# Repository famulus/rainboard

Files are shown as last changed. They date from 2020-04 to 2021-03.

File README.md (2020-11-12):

# rainboard

An open-source isomorphic MIDI controller.

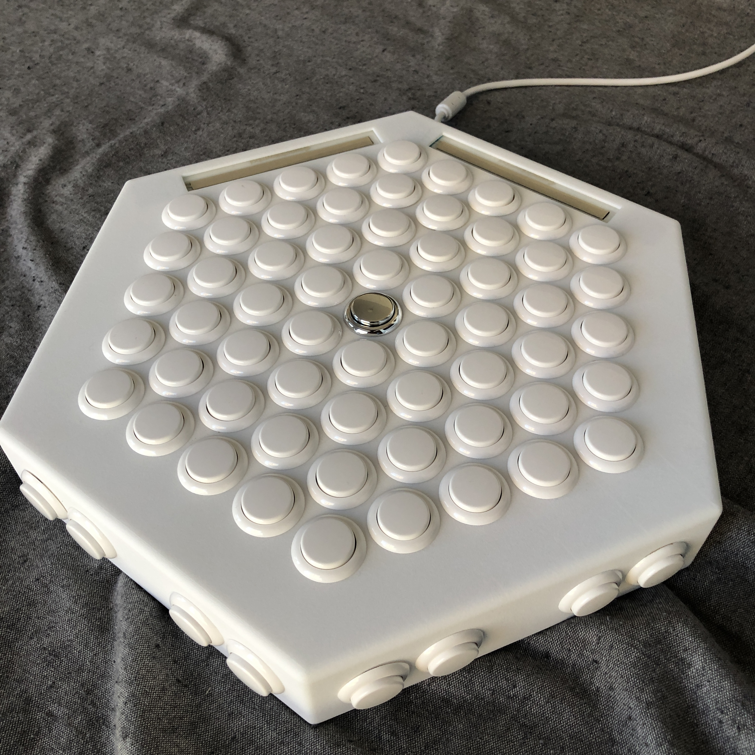
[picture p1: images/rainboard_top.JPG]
alt Rainboard


### Firmware Install:

The Rainboard firmware runs on an Arduino Mega which has two processors on board:
The main processor ( ATmega2560 ), and USB processor ( ATmega16U2 ). 

Requires an Arduino Mega with a 16U2 USB chip.

##### Installing the Rainboard firmware consists of two steps:

1. Flashing the USB controller, the ATmega16U2 with the `rainboard16U2.hex` file.
2. Uploading the main program `rainboard_firmware.ino` sketch to the Arduino Mega.

## Windows

#### Flash the USB Controller (ATmega16U2):

This can be accomplished with a DFU Programmer. Follow the instructions for your programmer.

Alternatively, if you don't have a DFU Programmer you can use Atmel FLIP software on a Windows Computer.

1. Go to http://www.atmel.com/tools/FLIP.aspx and download FLIP.
2. Install FLIP. Follow the installation wizard.
3. Disconnect Arduino from USB.
4. Jumper pins 5 and 6 on 16U2 ICSP header (as shown in fig.1). This will keep the 16U2 in RESET.
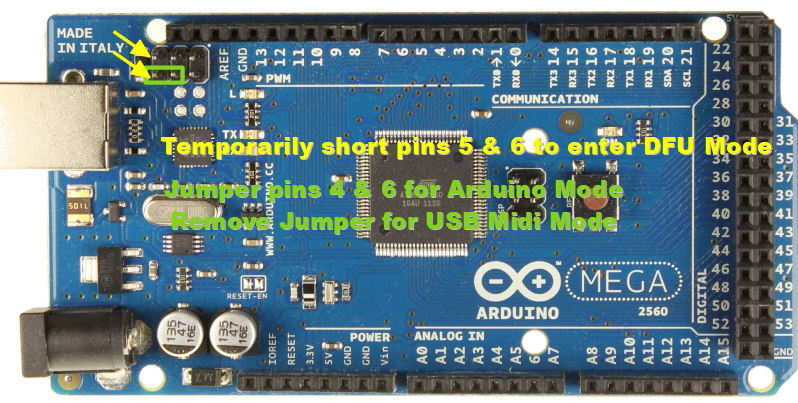
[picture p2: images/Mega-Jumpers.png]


5. Connect Arduino to USB.
6. Remove the jumper from pins 5 and 6. At this moment, 16U2 goes into DFU mode. A new USB device should be recognized.
7. If driver is not installed automatically, install it from `c:\Program Files\AtmelFlip 3.4.7\usb\`
8. Go to Device manager (Win+Pause -> (Hardware) -> Device Manager) and check if you can see the driver installed correctly. It will be located under Atmel USB Devices -> ATmega16U2.
9. Disconnect Arduino from USB. Jumper pins 5 and 6.
10. Connect Arduino to USB.
11. Remove the jumper from pins 5 and 6.
12. Start FLIP Software: Go to Start -> All Programs -> Flip -> Flip.
13. Go to Settings -> Communication -> USB.
14. Press “Open”.
15. Go to File -> Load HEX file and select the `rainboard16U2.hex` file.
16.  Press “Run”. This will program the 16U2 with the `rainboard16U2.hex` file.
17. Now close FLIP, disconnect and reconnect the Arduino, it should be recognized as a MIDI  device named Rainboard.

#### Upload firmware to the Arduino Mega (ATmega2560):

The easiest way to upload the firmware through the Arduino IDE. 
Make sure you have the proper drivers installed and that you can program the Mega from the Arduino IDE. 
You will also need two Arduino libraries installed that the Rainboard firmware depends on:

`Adafruit-MCP23017-Arduino-Library` - https://github.com/adafruit/Adafruit-MCP23017-Arduino-Library

`MIDI_Library-5.0.2` -  https://github.com/FortySevenEffects/arduino_midi_library

Make sure your Arduino environment is working, you have the two libraries installed and you can successfully compile the `rainboard_firmware.ino` sketch.  
Also make sure you have already flashed the ATmega16U2 with the `rainboard16U2.hex` file per the previous step.

1. Power down the Arduino. (unplug from host Computer)
2. Connect a jumper across pins 4 and 6 on the ICSP Header of the 16U2 (as shown in fig.1).


3. Reconnect the Arduino to the host Computer. It should appear as a COM Port Device in the Arduino IDE.
4. Now you can compile and upload the rainboard_firmware.ino sketch to the Arduino in the standard way.
5. After programming, power down (unplug from host Computer), remove the jumper from pins 4 and 6 on the   ICSP Header of the 16U2 (as shown in fig.1). The Arduino should now be fully programmed and ready to mate to the Rainboard. 
6. **Be very careful that all the pins are aligned and inserted properly before fully mating!**
7. Once the Arduino is mated to the Rainboard, reconnect it to the host PC and it should appear as a MIDI Device with the name Rainboard.

## Mac OS X

#### Flash the USB Controller (ATmega16U2):

Requires homebrew: https://brew.sh/

`brew install avrdude`

`cd [rainboard directory]/rainboard-firmware`

`avrdude -p at90usb82 -F -P usb -c usbtiny -U flash:w:rainboard16u2.hex -U lfuse:w:0xFF:m -U hfuse:w:0xD9:m -U efuse:w:0xF4:m -U lock:w:0x0F:m`

#### Upload firmware to the Arduino Mega (ATmega2560):

Same instructions as Windows.

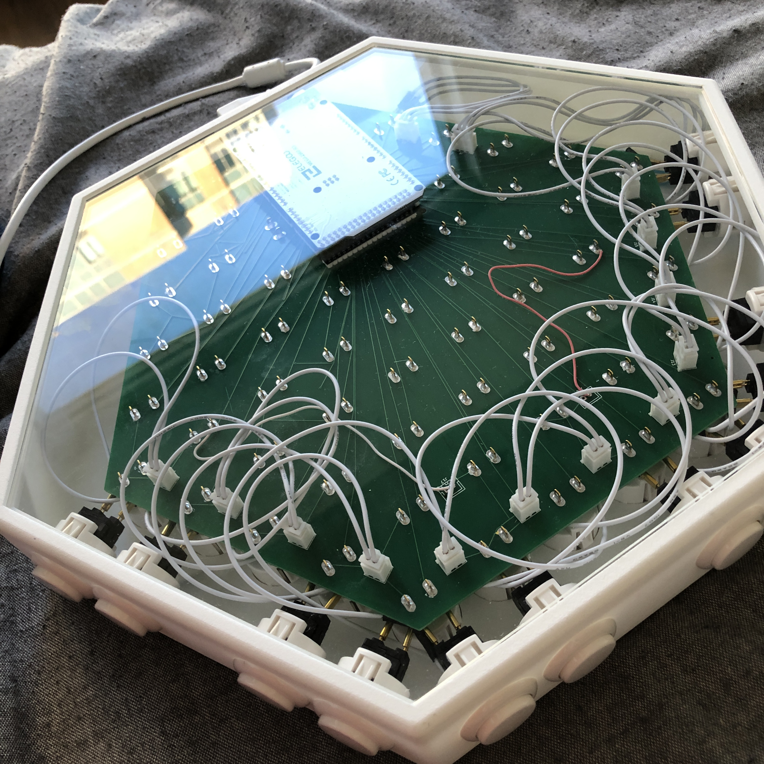
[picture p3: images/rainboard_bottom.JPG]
alt Rainboard


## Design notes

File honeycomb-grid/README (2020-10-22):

the folder uses a honeycomb-grid javascript library to generale the positions of the buttons.

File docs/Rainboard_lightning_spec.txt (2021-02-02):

Rainboard Lightning Spec

* Two versions of product will use same PCB: 

  Lightning:
    61 performance buttons (the buttons on top of unit)
    61 RGB LEDs (one LED under each button)
    12 meta-buttons (buttons on sides)
    2 softpots 
    2 MIDI DINs
    DC power input
    Sustain pedal in  
    Foot controller in
    Control Voltage out

  Thunder:
    61 main keys (RGB lEDs left unpopulated)
    USB only
    no external power supply

Take existing PCB and improve:

* Integrate Arduino Mega onto PCB.

* Implement input multiplexing (maybe remove IO expander if unnecessary).

* 61 LEDS and bypass caps.

* Power supply capable of powering 61 LEDS and Arduino, efficiently.

* When unit is powered with USB only, should still function, but without lights.

* move meta-button from front-sides to rear-sides.

* possibly engineer a better solution to connect metabuttons.

* engage programmer mode with meta buttons (or other solution).

* add 220 ohm Resistor to each button positive (for static discharge protection)?

* Redesign back panel for better aesthetic design.

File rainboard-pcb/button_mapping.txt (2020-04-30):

    button-38: D18  
    button-39: D19  
    button-44: D14  
    button-37: D17  
    button-33: A15  
    button-26: A9 A14,
    button-34: A13,
    button-35: A12  
    button-01: D31  
    button-09: D40,
    button-17: D49  
    button-25: A11 D52,
    button-41: A10  
    button-49: A5,
    button-57: D11  
    button-02: D36,
    button-10: D45  
    button-18: D51,
    button-42: A8  
    button-50: A6  
    button-58: D12,
    button-03: D38,
    button-11: D50,
    button-19: D24,
    button-27: D13,
    button-43: A7,
    button-51: D10,
    button-59: D7,
    button-04: D42,
    button-12: D26,
    button-20: D25,
    button-28: D23,
    button-36: D16  
    button-52: D9,
    button-60: A0,
    button-05: D46  
    button-13: D29,
    button-21: D28,
    button-29: D22  
    button-45: D4  
    button-53: D8  
    button-61: A2,
    button-06: D30,
    button-14: D33,
    button-22: D34  
    button-30: D27  
    button-46: D15,
    button-54: D6  
    button-07: D32  
    button-15: D39,
    button-23: D41  
    button-31: D35  
    button-47: D5  
    button-55: A1,
    button-08: D37  
    button-16: D44,
    button-24: D48  
    button-32: D47  
    button-40: D43,
    button-48: A4  
    button-56: A3

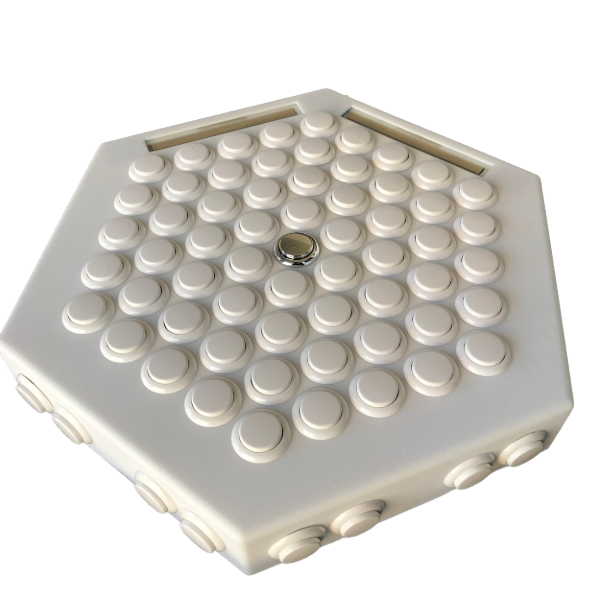
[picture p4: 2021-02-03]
website/img/not-using/rainboard_top_low-rez.png

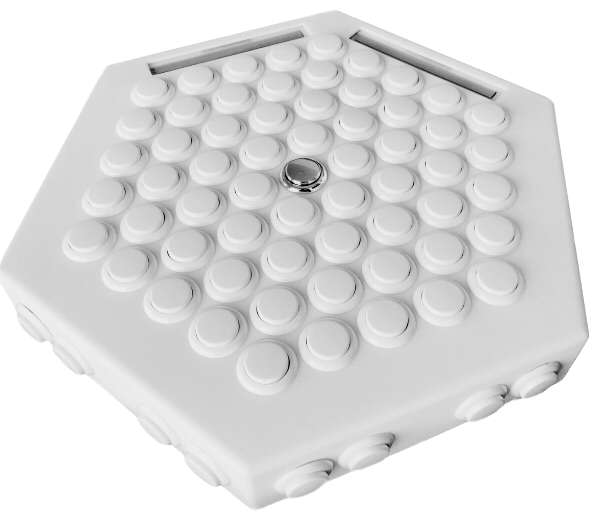
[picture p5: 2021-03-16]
website/img/rainboard-midi-controller.png

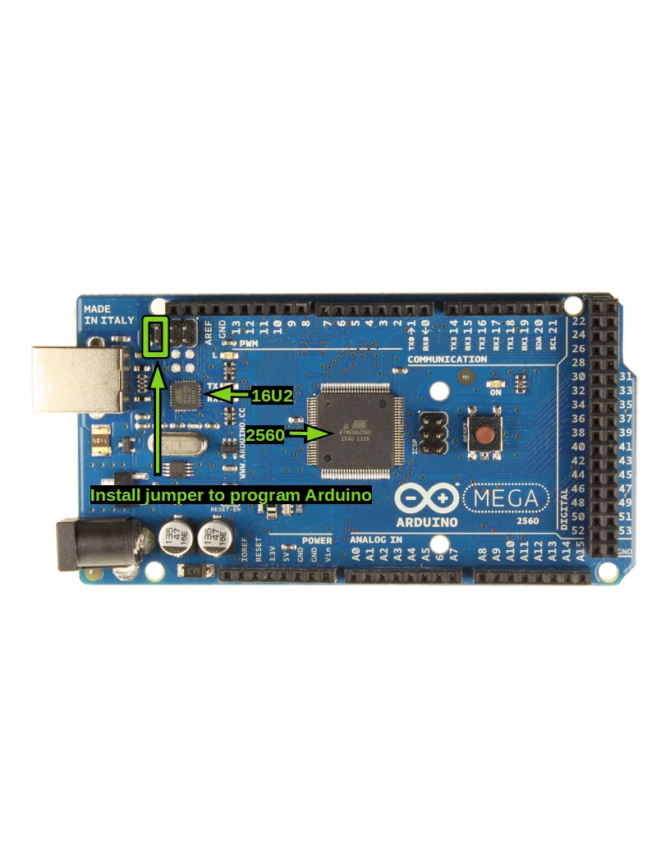
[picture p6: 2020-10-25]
images/Arduino-Mega-Photo.jpg

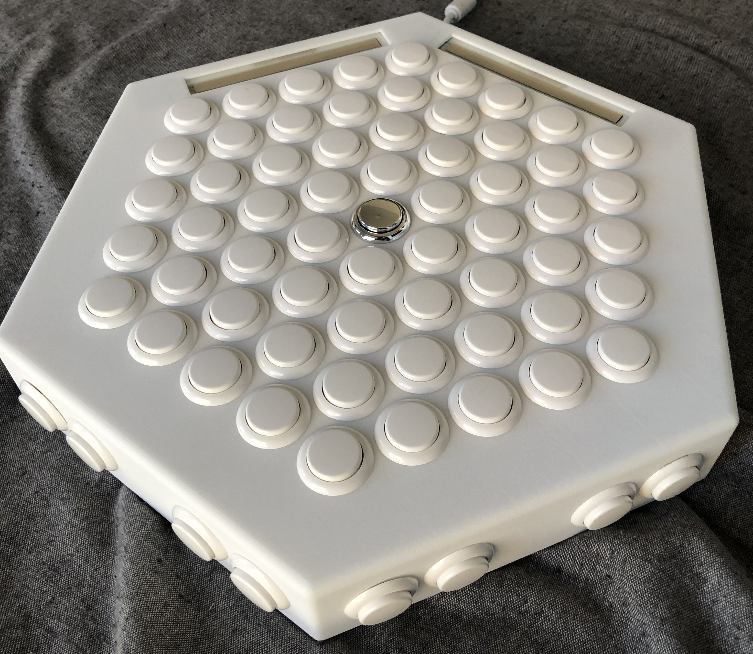
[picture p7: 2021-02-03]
website/img/not-using/rainboard_top-cropped.jpeg

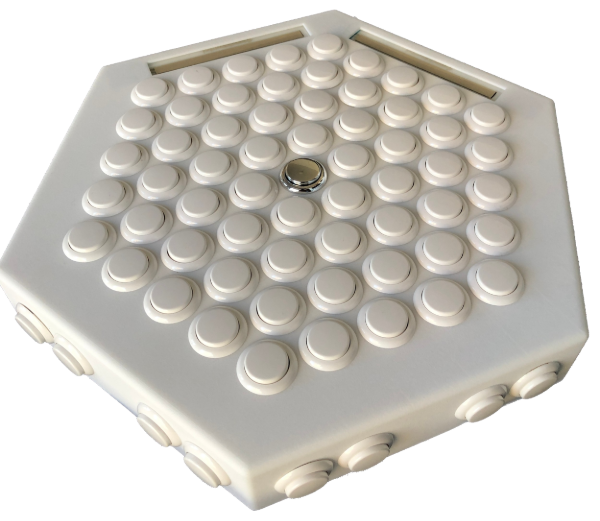
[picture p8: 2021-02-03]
website/img/not-using/rainboard_top-cropped.png

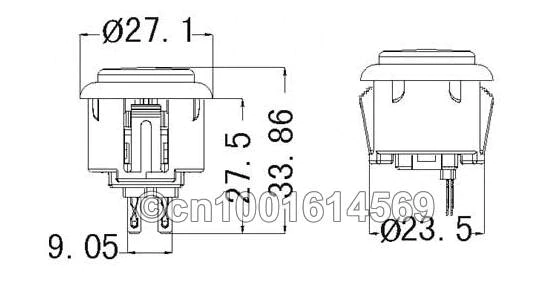
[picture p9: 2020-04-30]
honeycomb-grid/sanwa_drawing.webp

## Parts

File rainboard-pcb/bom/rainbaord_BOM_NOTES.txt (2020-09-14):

midi interface:
https://calcium3000.wordpress.com/projects/teensy-midi-interface/

io expander:
https://datasheet.lcsc.com/szlcsc/Microchip-Tech-MCP23017-E-SO_C47023.pdf
https://www.best-microcontroller-projects.com/mcp23017.html

1uf caps:

https://datasheet.lcsc.com/szlcsc/Samsung-Electro-Mechanics-CL21B105KBFNNNE_C28323.pdf

100k resistor:

https://lcsc.com/product-detail/Chip-Resistor-Surface-Mount_Uniroyal-Elec-1206W4F1003T5E_C17900.html/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

10K resistor:

1206W4F1002T5E
https://datasheet.lcsc.com/szlcsc/Uniroyal-Elec-1206W4F1002T5E_C17902.pdf

4.7K
0603WAF4701T5E

softpot connectors:
https://learn.sparkfun.com/tutorials/softpot-hookup-guide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

schmitt trigger:
https://calcium3000.wordpress.com/projects/teensy-midi-interface/
https://components101.com/articles/schmitt-trigger-introduction-working-applications
https://datasheet.lcsc.com/szlcsc/Nexperia-74HCT14D-653_C5967.pdf

optocoupler:
https://hackaday.com/2018/05/09/optocouplers-defending-your-microcontroller-midi-and-a-hot-tip-for-speed/
https://datasheet.lcsc.com/szlcsc/Everlight-Elec-EL357N-B-TA-G_C6649.pdf

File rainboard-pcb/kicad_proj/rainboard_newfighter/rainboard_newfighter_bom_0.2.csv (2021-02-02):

Component | Description | Part | References | Value | Footprint | Quantity Per PCB | Datasheet | LCSC | PN
1 | Unpolarized capacitor | C | C7 C9 C13 C18 C29 C30 C32 C34 C35 C37 C40 C41 C44 C45 C46 C49 C50 C65 C66 C67 C68 C69 C70 C71 C72 C73 C74 C75 C76 C77 C78 C79 C80 C81 C82 C83 C84 C85 C86 C87 C88 C89 C90 C91 C92 C93 C94 C95 C96 C97 C98 C99 C100 C101 C102 C103 C104 C105 C106 C107 C108 C109 C110 C111 C112 C113 C114 C115 C116 C117 C118 C119 C120 C121 | 100nf | C_0603_1608Metric | 74 | ~ | C14663 | CC0603KRX7R9BB104
2 | Unpolarized capacitor | C | C3 C4 C6 C21 C22 C24 C25 C26 C27 C55 C56 C57 C58 C59 C60 C61 C62 C63 C64 | 10uF 25V | C_1206_3216Metric | 19 | ~ |  | CL21B105KBFNNNE
3 | Unpolarized capacitor | C | C5 C8 C10 C11 C12 C14 C16 C17 C20 C23 C31 C33 C36 C38 C39 C43 C47 C48 | 1uF 25V | C_0805_2012Metric | 18 | ~ |  | CL21B105KBFNNNE
4 | Polarized capacitor | CP | C15 C19 C28 C42 C51 C52 C53 C54 | 470uF 25V | CP_Elec_10x10 | 8 | ~ |  | UCW1E471MNL1GS
5 | Unpolarized capacitor | C | C1 C2 | DNP-1uF 25V | C_0805_2012Metric | 2 | ~ |  | DNP-CL21B105KBFNNNE
6 | Zener diode | D_Zener | D1 D6 | 12Vw | D_SMA | 2 | ~ |  | SMAJ12A
7 | Schottky diode | D_Schottky | D8 D10 D11 D12 D16 D17 D18 | 40V 1A | D_SOD-123 | 7 | ~ |  | PMEG4010EGWJ
8 | Dual Zener diode, common anode on pin 3 | D_Zener_x2_ACom_KKA | D2 D3 D4 D9 D13 D14 D15 | 5Vw | SOT-23 | 7 | ~ |  | S2305TR
9 | Zener diode | D_Zener | D5 D7 | 5Vw | D_SMA | 2 | ~ |  | SMAJ5.0A
10 | RGB LED with integrated controller | WS2812B | D19 D20 D21 D22 D23 D24 D25 D26 D27 D28 D29 D30 D31 D32 D33 D34 D35 D36 D37 D38 D39 D40 D41 D42 D43 D44 D45 D46 D47 D48 D49 D50 D51 D52 D53 D54 D55 D56 D57 D58 D59 D60 D61 D62 D63 D64 D65 D66 D67 D68 D69 D70 D71 D72 D73 D74 D75 | WS2812B | LED_WS2812B_PLCC4_5.0x5.0mm_P3.2mm | 57 | https://cdn-shop.adafruit.com/datasheets/WS2812B.pdf |  | WS2812B
11 | Resettable fuse, polymeric positive temperature coefficient | Polyfuse | F2 | 15V .5A | Fuse_1812_4532Metric | 1 | ~ |  | MF-MSMF050-2
12 | Resettable fuse, polymeric positive temperature coefficient | Polyfuse | F1 | 20V 3A | Fuse_1812_4532Metric | 1 | ~ |  | TLC-MSMD150/20
13 | Ferrite bead | Ferrite_Bead | FB1 FB2 FB3 | 4A Ferrite | L_1206_3216Metric | 3 | ~ |  | 742792115
14 | Generic connector, single row, 01x02, script generated (kicad-library-utils/schlib/autogen/connector/) | Conn_01x02_Female | J4 J5 J6 J7 J8 J9 J10 J11 J12 J13 J14 J15 J16 J17 J18 J20 | Conn_01x02_Female | JST_XH_B2B-XH-A_1x02_P2.50mm_Vertical | 16 | ~ |  | B2B-XH-A(LF)(SN)
15 | Generic connector, single row, 01x03, script generated (kicad-library-utils/schlib/autogen/connector/) | Conn_01x03 | J22 J23 | Conn_01x03 | JST_XH_B3B-XH-AM_1x03_P2.50mm_Vertical | 2 | ~ |  | B3B-XH-AM
16 | DC Barrel Jack with an internal switch | Barrel_Jack_Switch | J1 | EJ508A | BarrelJack_Horizontal | 1 | ~ |  | EJ508A
17 | Generic connector, double row, 02x03, odd/even pin numbering scheme (row 1 odd numbers, row 2 even numbers), script generated (kicad-library-utils/schlib/autogen/connector/) | Conn_02x03_Odd_Even | J21 J24 J25 | PH2-06-UA | PinHeader_2x03_P2.54mm_Vertical | 3 | ~ |  | PH2-06-UA
18 | CONN RCPT FMALE DIN 5POS SOLDER | SDS-50J | J2 J19 | SDS-50J | CUI_SDS-50J | 2 | CUI Inc |  | SDS-50J
19 | USB Type B connector | USB_B | J3 | USB_B | UJ2-BH-1-TH | 1 | ~ |  | UJ2-BH-1-TH
20 | Jumper, normally closed | Jumper | JP1 JP2 JP3 JP4 JP5 | Jumper | SolderJumper-2_P1.3mm_Bridged_Pad1.0x1.5mm | 5 | ~ |  | Virtual
21 | Inductor | L | L2 L4 L5 | 10uH .5Ohm | INDC250X180X200L50N | 3 | ~ |  | CBC2518T100K
22 | Inductor | L | L1 L3 | 27uH | L_12x12mm_H8mm | 2 | ~ |  | SRR1210-270M
23 | Generic PowerPAK-8 1212-8 | NMOS_SGD_123_4_5 | Q1 | 30V 10mOhm | PowerPAK_SO-8_Single | 1 |  |  | SI7114ADN-T1-GE3
24 | Dual NMOS transistor, 6 pin package | Q_DUAL_NMOS_S1G1D2S2G2D1 | Q2 Q3 | DUAL 30V NMOS | SOT-363_SC-70-6 | 2 |  |  | DMN3190LDW
25 | Resistor | R | R7 R13 R14 R17 R19 R35 R36 | 100k | R_0603_1608Metric | 7 | ~ | C25803 | RC0603JR-07100KL
26 | Resistor | R | R2 R3 R4 R5 R6 R11 R25 R42 R43 R47 R49 R51 R53 | 11R | R_0603_1608Metric | 13 | ~ | C227565 | RC0603JR-0711RL
27 | Resistor | R | R10 R12 R20 R22 R23 R24 R28 R29 R31 R32 R39 R40 R48 R50 R52 | 19.1k | R_0603_1608Metric | 15 | ~ | C22897 | RC0603FR-0719K1L
28 | Resistor | R | R1 R8 R15 R21 R26 R54 R55 R56 R57 R58 R59 R60 R61 R62 R63 R64 R65 R66 R67 R68 R69 R70 R71 R72 R73 R74 R75 R76 R77 R78 R79 R80 R81 R82 R83 R84 R85 R86 R87 R88 R89 R90 R91 R92 R93 R95 R96 R97 R98 R99 R100 R101 R102 R103 R104 R105 R106 R107 R108 R109 R110 | 210R | R_0805_2012Metric | 61 | ~ | C228630 | RC0603FR-07210RL
29 | Resistor | R | R111 R112 R113 R114 R115 R116 R117 R118 R119 R120 R121 R122 R123 R124 R125 R126 R127 R128 R129 R130 R131 R132 R133 R134 R135 R136 R137 R138 R139 R140 R141 R142 R143 R144 R145 R146 R147 R148 R149 R150 R151 R152 R153 R154 R155 R156 R157 R158 R159 R160 R161 R162 R163 R164 R165 R166 R167 | 210R | R_0805_2012Metric | 57 | ~ | C228630 | RC0603FR-07210RL
30 | Resistor | R | R9 R18 R27 R30 R33 R34 R37 R38 R41 R44 R46 | 4.7k | R_0603_1608Metric | 11 | ~ | C23162 | RC0603JR-074K7L
31 | Resistor | R | R16 | DNP-210R | R_0805_2012Metric | 1 | ~ | DNP-C228630 | RC0603FR-07210RL
32 | Resistor | R | R45 | DNP-4.7k | R_0603_1608Metric | 1 | ~ | DNP-C23162 | RC0603JR-074K7L
33 | 24mm Joystick Button | SANWA-OBSF24 | SW1 SW2 SW3 SW4 SW5 SW6 SW7 SW8 SW9 SW10 SW11 SW12 SW13 SW14 SW15 SW16 SW17 SW18 SW19 SW20 SW21 SW22 SW23 SW24 SW25 SW26 SW27 SW28 SW29 SW30 SW31 SW32 SW33 SW34 SW35 SW36 SW37 SW38 SW39 SW40 SW41 SW42 SW43 SW44 SW45 SW46 SW47 SW48 SW49 SW50 SW51 SW52 SW53 SW54 SW55 SW56 SW57 | SANWA-OBSF24 | Sanwa-OBSF24-v2 | 57 |  |  | SANWA-OBSC-CW/W
34 | Single High Speed LSTTL/TTL Compatible Optocoupler with enable, dV/dt 1000/us, VCM 10, max 7V VCC, DIP-8 | 6N137 | U1 | 6N137 | COUPL_6N138SDM | 1 | https://www.onsemi.com/pub/Collateral/HCPL2631M-D.pdf |  | 6N137SDM
35 | Hex inverter schmitt trigger | 74HC14 | U3 | 74HC14 | TSSOP-14_4.4x5mm_P0.65mm | 1 | http://www.ti.com/lit/gpn/sn74HC14 |  | 74HC14PW-Q100,118
36 | 16MHz, 16kB Flash, 512B SRAM, 512B EEPROM, QFN-32 | ATmega16U2-MU | U4 U5 | ATmega16U2-MU | QFN-32-1EP_5x5mm_P0.5mm_EP3.1x3.1mm | 2 | http://ww1.microchip.com/downloads/en/DeviceDoc/doc7799.pdf |  | ATMEGA16U2-MUR
37 | 8MHz, 64kB Flash, 8kB SRAM, 4kB EEPROM, JTAG, TQFP-100 | ATmega2560-16AU | U6 | ATmega2560-16AU | TQFP-100_14x14mm_P0.5mm | 1 | http://ww1.microchip.com/downloads/en/DeviceDoc/Atmel-2549-8-bit-AVR-Microcontroller-ATmega640-1280-1281-2560-2561_datasheet.pdf |  | ATMEGA2560-16AUR
38 | Buck Switching Regulator IC Positive Adjustable 0.8V 1 Output 6A 8-SOIC (0.154", 3.90mm Width) Exposed Pad | RT8298 | U2 | RT8298 | SOIC-8-1EP_3.9x4.9mm_P1.27mm_EP2.41x3.3mm_ThermalVias | 1 | ~ |  | RT8298ZSP
39 | Three pin ceramic resonator | Resonator | Y1 Y2 Y3 | 16MHz | Resonator_SMD_muRata_CSTxExxV-3Pin_3.0x1.1mm | 3 | ~ |  | CSTNE16M0V530000R0
Component Groups: | 39
Component Count: | 471
Fitted Components: | 471
Number of PCBs: | 1
Total components: | 471
Schematic Version: | 0.2
Schematic Date:
PCB Variant: | default
BoM Date: | 1/14/2021 10:12:15 AM
Schematic Source: | rainboard_newfighter.sch
KiCad Version: | Eeschema (5.1.5)-3

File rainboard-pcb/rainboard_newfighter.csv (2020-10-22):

Comment | Designator | Footprint | LCSC
100nf | C1,C2,C3,C4 | Capacitor_SMD:C_0603_1608Metric | C14663
D | D1 | Diode_SMD:D_SMA | C95872
Conn_01x02 | J1,J2,J3,J4,J5,J6,J7,J8,J13,J14,J15,J16,J17,J18 | Connector_JST:JST_XH_B2B-XH-AM_1x02_P2.50mm_Vertical
Conn_01x03 | J9,J10 | Connector_JST:JST_XH_B3B-XH-AM_1x03_P2.50mm_Vertical
SDS-50J | J11,J12 | MIDI-DIN:CUI_SDS-50J
100k | R1,R2 | Resistor_SMD:R_0603_1608Metric | C25803
4.7k | R3,R4,R9,R10 | Resistor_SMD:R_0603_1608Metric | C23162
220R | R5,R6,R7 | Resistor_SMD:R_0603_1608Metric | C22962
10k | R8 | Resistor_SMD:R_0603_1608Metric | C25804
SANWA-OBSF24 | S1,S2,S3,S4,S5,S6,S7,S8,S9,S10,S11,S12,S13,S14,S15,S16,S17,S18,S19,S20,S21,S22,S23,S24,S25,S26,S27,S28,S29,S30,S31,S32,S33,S34,S35,S36,S37,S38,S39,S40,S41,S42,S43,S44,S45,S46,S47,S48,S49,S50,S51,S52,S53,S54,S55,S56,S57,S58,S59,S60,S61 | rainboard_newfighter:Sanwa-OBSF24-v2
MCP23017-E_SO | U1 | io_expander:SOIC127P1030X265-28N | C47023
74HC14D | U2 | schmitt_trigger:SOIC127P600X175-14N | C5605
EL357N(A)(TA)-G | U3 | opto_coupler:SOP254P700X200-4N | C142286
Arduino_Mega2560_Shield | XA1 | arduno_mega:Arduino_Mega2560_Shield

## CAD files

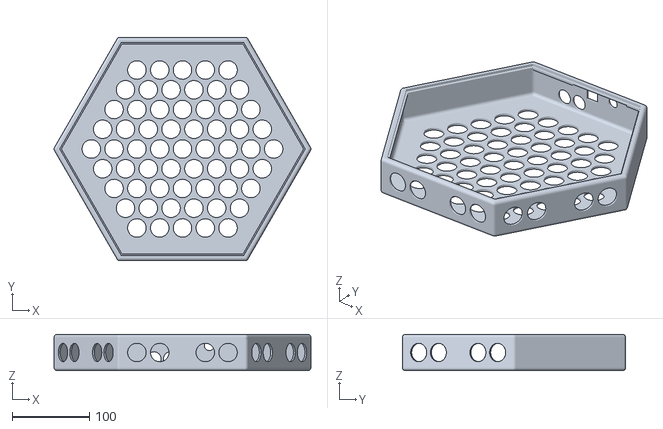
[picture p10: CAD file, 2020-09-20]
3D_Printed_chassis/rainboard_chassis.stl
332.6 x 289.1 x 46.9

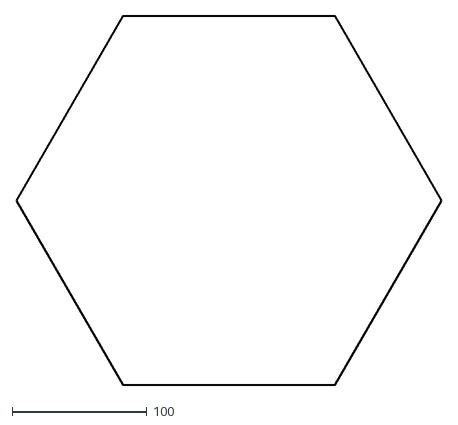
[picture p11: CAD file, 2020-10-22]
rainboard-chassis/lightning/plexi_bottom.dxf
316.4 x 274.0

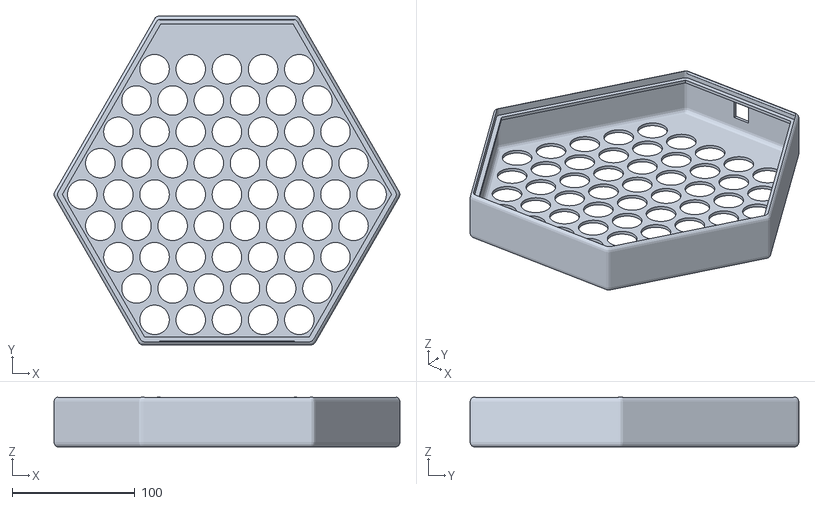
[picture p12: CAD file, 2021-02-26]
rainboard-chassis/thunder/rainboard_chassis_thunder.stl
282.1 x 268.2 x 40.7

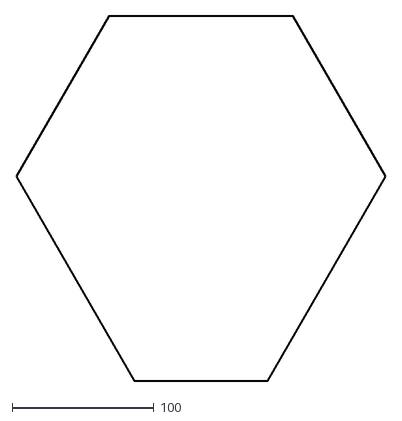
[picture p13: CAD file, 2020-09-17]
rainboard-pcb/edgecut.dxf
260.0 x 256.6

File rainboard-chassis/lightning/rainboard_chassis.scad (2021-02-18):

round_over = 4;
wall_thickness = 3 ;

rainboad_diameter = 332.55  ; // point to point, long diagonal  288 short diag
rainboard_height = 41;

hole_radius = 12;

resolution = 100;

back_panel = [125,40,60];

foot_inset = 15;





module backPanel(dimentions=[1,2,3]) {

  midi_opening = 18.5; //diameter
  midi_horizontal_offset = 38.9735;    
  usb_width = 14.5;    //cube_width
  usb_opening = [usb_width,usb_width,10] ;
  
  dc_power_opening = 13; // diameter
  dc_power_horizontal_offset = -38.1765;    
  
  top_of_chassis_to_top_of_pcb = 25;    
  
  pcb_offset = top_of_chassis_to_top_of_pcb -(rainboard_height/2);
  
  translate([0,((288/2)-1.5),pcb_offset]) rotate([90,0,0]){ // place all holes at the back panel
    
   translate([ 0, -(usb_width/2),0]) cube(usb_opening, center=true); // cutout for USB
   translate([midi_horizontal_offset,-(dc_power_opening/2),0]) cylinder(20, d=(dc_power_opening), center=true,$fn=resolution);  // cutout for power   

   translate([dc_power_horizontal_offset,-(midi_opening/2),0]) cylinder(20, d=(midi_opening), center=true,$fn=resolution);   // midi OUT  
   
 }   
 

}



module mainBody(rainboard_height,rainboad_diameter, round_over ) {

  minkowski(){
    
    //            main body
    
    cylinder(h=rainboard_height-(round_over*2), d=(rainboad_diameter- (round_over*2)), center=true,$fn=6);     
    
    //            round over
    sphere(round_over, $fn=resolution);

  }

}


module interior(rainboard_height,rainboad_diameter, round_over, wall_thickness ) {

  //        interior
  
  translate([0,0,0])
  minkowski(){
    
    //            interior hex
    //        cylinder(h=(rainboard_height+ wall_thickness), d=(rainboad_diameter - wall_thickness), center=true,$fn=6);
    cylinder(h=rainboard_height-(round_over*2)-(wall_thickness*2) , d=((rainboad_diameter- (round_over*2)) -(wall_thickness*2) ), center=true,$fn=6);     

    
    //            round over
    sphere(round_over, $fn=resolution);

  };

}

module footer_cutout(rainboard_height,rainboad_diameter, foot_inset ) {
  translate([0,0,foot_inset])
  cylinder(h=rainboard_height+foot_inset , d=(rainboad_diameter-foot_inset), center=true,$fn=6);     


}



module buttons(buttons ) {

  //    button
  
  
  for(i = buttons){
    translate([i[0],i[1],-50])cylinder(r=12, h=100, $fn=resolution);
  };
}





module ledge( ) {    // ledge for plexiglass

  plexi_thickness = 3; 
  recess = 2; 

  difference (){
    
   translate([0,0,  (rainboard_height/2 - (plexi_thickness/2)-plexi_thickness-recess)  ])    cylinder(h=plexi_thickness , d=(rainboad_diameter  ), center=true,$fn=6);   // the ledge  
   


   translate([0,0,rainboard_height/2 - 3-2])   cylinder(h=20 , d=(rainboad_diameter-foot_inset-4), center=true,$fn=6);     // the cutout negative



 }

}




module sideButtons(buttons ) {

  //    button
  for(i = [-2:2]){
    if(i != 0){
      translate([i*29.5,-100,0]) rotate([90,0,0])  cylinder(r=12, h=100, $fn=resolution);
    }
  }
}













module modulation_strips_positive( ) {


  //  https://cdn-shop.adafruit.com/product-files/178/SOFTPOT-DATA-SHEET-Rev-F3.pdf
  tolerance = 1;
  half_tolerance = tolerance /2;
  ribbonLength =  115.86+ tolerance;
  ribbonWidth = 20.32+ tolerance;
  ribbonThickness = 0.58+ tolerance;
  tailLength = 24.89+ tolerance;
  tailWidth  = 10.16+ tolerance;    
  softpot_backer =     2;
  softpot_wall_thickness = 1.5;


  rotate([0,180,0]) 
  translate([0,288/2-16.7,
    ((rainboard_height/2)-(softpot_wall_thickness*2))
    ])
  cube(
    [
    ribbonLength+(softpot_wall_thickness*2),
    ribbonWidth+(softpot_wall_thickness*2.5),
    softpot_backer+(softpot_wall_thickness)
    ]
    , true); // enclosing cuboid
  
  
  rotate([0,180,300]) 
  translate([0,288/2-16.7,
    ((rainboard_height/2)-(softpot_wall_thickness*2))
    ])
  cube(
    [
    ribbonLength+(softpot_wall_thickness*2),
    ribbonWidth+(softpot_wall_thickness*2.5),
    softpot_backer+(softpot_wall_thickness)
    ]
    , true); // enclosing cuboid
  
  
}





module modulation_strips_negative( ) {


  //  https://cdn-shop.adafruit.com/product-files/178/SOFTPOT-DATA-SHEET-Rev-F3.pdf
  tolerance = 1;
  half_tolerance = tolerance /2;
  ribbonLength =  115.86+ tolerance;
  ribbonWidth = 20.32+ tolerance;
  ribbonThickness = 0.58+ tolerance;
  tailLength = 24.89+ tolerance;
  tailWidth  = 10.16+ tolerance;    
  slot_height =     1.6;
  slot_runout = 46;    
  active_area_width =   15;
  active_area_length =   110;  
  softpot_wall_thickness = 1.5;


  rotate([0,180,0]) 
  translate([0,288/2-16.7,
    ((rainboard_height/2)-(softpot_wall_thickness)-softpot_wall_thickness/2)
    ]){
    
    cube([ribbonLength+slot_runout,ribbonWidth,slot_height], true); // slot for ribbon

    translate([0,0,10])cube([active_area_length,active_area_width,20], true); // smaller cutout for active area
  }
  
  
  rotate([0,180,300]) 
  translate([0,288/2-16.7,
    ((rainboard_height/2)-(softpot_wall_thickness)-softpot_wall_thickness/2)
    ]){
    
    cube([ribbonLength+slot_runout,ribbonWidth,slot_height], true); // slot for ribbon

    translate([0,0,10])cube([active_area_length,active_area_width,20], true); // smaller cutout for active area
  }
  
  



}

















//  Final Output
difference(){
  difference(){
    mainBody(rainboard_height,rainboad_diameter, round_over );                   
    interior(rainboard_height,rainboad_diameter, round_over, wall_thickness );
  };
  
  footer_cutout(rainboard_height,rainboad_diameter, foot_inset);

  backPanel(back_panel);

  
  rotate([0,0,120])sideButtons();
  rotate([0,0,240])sideButtons();
  rotate([0,0,0])sideButtons();
  


  buttons(buttons_coordinates);

  backPanel();

  
  modulation_strips_negative();

};

ledge();


difference (){
  modulation_strips_positive();
  modulation_strips_negative();

}




buttons_coordinates =

[
[  -117.98730101159192,  0 ],
[  -103.23888838514293,  25.545 ],
[  -88.49047575869395,  51.09 ],
[  -73.74206313224495,  76.635 ],
[  -58.99365050579596,  102.18 ],
[  -103.23888838514293,  -25.545 ],
[  -88.49047575869395,  0 ],
[  -73.74206313224495,  25.545 ],
[  -58.99365050579596,  51.09 ],
[  -44.24523787934697,  76.635 ],
[  -29.49682525289798,  102.18 ],
[  -88.49047575869395,  -51.09 ],
[  -73.74206313224495,  -25.545 ],
[  -58.99365050579596,  0 ],
[  -44.24523787934697,  25.545 ],
[  -29.49682525289798,  51.09 ],
[  -14.74841262644899,  76.635 ],
[  0,  102.18 ],
[  -73.74206313224495,  -76.635 ],
[  -58.99365050579596,  -51.09 ],
[  -44.24523787934697,  -25.545 ],
[  -29.49682525289798,  0 ],
[  -14.74841262644899,  25.545 ],
[  0,  51.09 ],
[  14.74841262644899,  76.635 ],
[  29.49682525289798,  102.18 ],
[  -58.99365050579596,  -102.18 ],
[  -44.24523787934697,  -76.635 ],
[  -29.49682525289798,  -51.09 ],
[  -14.74841262644899,  -25.545 ],
[  0,  0 ],
[  14.74841262644899,  25.545 ],
[  29.49682525289798,  51.09 ],
[  44.24523787934697,  76.635 ],
[  58.99365050579596,  102.18 ],
[  -29.49682525289798,  -102.18 ],
[  -14.74841262644899,  -76.635 ],
[  0,  -51.09 ],
[  14.74841262644899,  -25.545 ],
[  29.49682525289798,  0 ],
[  44.24523787934697,  25.545 ],
[  58.99365050579596,  51.09 ],
[  73.74206313224495,  76.635 ],
[  0,  -102.18 ],
[  14.74841262644899,  -76.635 ],
[  29.49682525289798,  -51.09 ],
[  44.24523787934697,  -25.545 ],
[  58.99365050579596,  0 ],
[  73.74206313224495,  25.545 ],
[  88.49047575869395,  51.09 ],
[  29.49682525289798,  -102.18 ],
[  44.24523787934697,  -76.635 ],
[  58.99365050579596,  -51.09 ],
[  73.74206313224495,  -25.545 ],
[  88.49047575869395,  0 ],
[  103.23888838514293,  25.545 ],
[  58.99365050579596,  -102.18 ],
[  73.74206313224495,  -76.635 ],
[  88.49047575869395,  -51.09 ],
[  103.23888838514293,  -25.545 ],
[  117.98730101159192,  0 ]
];

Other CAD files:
rainboard-chassis/thunder/rainboard_chassis_thunder.scad

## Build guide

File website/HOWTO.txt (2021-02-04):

TO DEPLOY UPDATES TO SURGE:
====================

Deploying first time? Get surge:

$ npm install --global surge

Learn more:
https://surge.sh/help/getting-started-with-surge

Deploy:

$ surge --domain https://rainboard.surge.sh

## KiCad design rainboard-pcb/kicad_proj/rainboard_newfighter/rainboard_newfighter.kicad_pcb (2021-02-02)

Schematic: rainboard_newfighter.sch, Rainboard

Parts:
C1, C2: DNP-1uF 25V
C5, C10, C14, C17, C23, C31, C33, C36, C38, C39, C43, C47, C48: 1uF 25V; C_0805_2012Metric
C7, C13, C18, C29, C30, C32, C34, C35, C37, C40, C41, C44, C45, C46, C49, C50: 100nf; C_0603_1608Metric; LCSC C14663
C11: 1uF 25V
C15, C19, C42: 470uF 10V; CP_Elec_6.3x7.7
D1, D6: 6V; SOT23-3
D2, D4, D9, D13, D14, D15: 5Vw; SOT-23
D3: 5Vw
D5, D7: 5Vw; D_SMA
D10, D11, D12, D16, D17, D18: 40V 1A; D_SOD-123
F1: 12V 5A; Fuse_2010_5025Metric
F2: 15V .5A; Fuse_1812_4532Metric
FB1, FB3: 4A Ferrite; L_1206_3216Metric
FB2: 10A Ferrite; L_1210_3225Metric
J1: 54-00167; BarrelJack_Horizontal
J2: SDS-50J
J3: USB_B; UJ2-BH-1-TH
J4, J5, J6, J7, J8, J9, J10, J11, J12, J13, J14, J16: Conn_01x02_Female; JST_XH_B2B-XH-A_1x02_P2.50mm_Vertical
J15: SDS-50J; CUI_SDS-50J
J17, J20, J21: PH2-06-UA; PinHeader_2x03_P2.54mm_Vertical
J18, J19: Conn_01x03; JST_XH_B3B-XH-AM_1x03_P2.50mm_Vertical
JP1, JP2, JP3, JP4, JP5: Jumper; SolderJumper-2_P1.3mm_Bridged_Pad1.0x1.5mm
L1: 27uH; L_12x12mm_H8mm
L2, L4, L5: 10uH .5Ohm; INDC250X180X200L50N
Q2, Q3: DUAL 30V NMOS; SOT-363_SC-70-6
R1, R8: 210R; LCSC C228630
R2, R3, R5, R6, R11, R25, R42, R43, R47, R49, R51, R53: 11R; R_0603_1608Metric; LCSC C227565
R4: 11R; LCSC C227565
R9, R18, R27, R30, R33, R34, R37, R38, R41, R44, R46: 4.7k; R_0603_1608Metric; LCSC C23162
R10, R12, R22, R23, R24, R28, R29, R31, R32, R39, R40, R48, R50, R52: 19.1k; R_0603_1608Metric; LCSC C22897
R14, R35, R36: 100k; R_0603_1608Metric; LCSC C25803
R15, R21, R26: 210R; R_0805_2012Metric; LCSC C228630
R16: DNP-210R; R_0805_2012Metric; LCSC DNP-C228630
R45: DNP-4.7k; R_0603_1608Metric; LCSC DNP-C23162
TP1, TP2, TP3, TP4, TP5, TP6, TP7, TP8, TP9, TP10, TP11, TP12, TP13, TP14, TP15, TP16, TP17, TP18, TP19, TP20, TP21, TP22, TP23, TP24, TP25, TP26: TestPoint; TestPoint_Pad_1.0x1.0mm
U1: 6N137
U3: 74HC14; TSSOP-14_4.4x5mm_P0.65mm
U4: ATmega16U2-MU; QFN33P50_500X500X60L40X24T300N
U5: ATmega16U2-MU; QFN-32-1EP_5x5mm_P0.5mm_EP3.1x3.1mm
U6: ATmega2560-16AU; TQFP-100_14x14mm_P0.5mm
Y1, Y2, Y3: 16MHz; Resonator_SMD_muRata_CSTxExxV-3Pin_3.0x1.1mm

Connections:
5VA_MCU: C41.1, C42.1, L5.1, R37.1, U6.100 (AVCC)
5V_MCU: C11.1, C17.1, C19.1, C23.1, C36.1, C37.1, C39.1, C40.1, C48.1, C49.1, D10.1 (K), D11.1 (K), D16.1 (K), D17.1 (K), D18.1 (K), J17.2, J20.2, J21.2, L5.2, R8.2, R9.1, R18.1, R25.1, R27.1, R30.1, R39.1, R40.1, R46.1, R48.2, U1.7 (EN), U1.8 (VCC), U3.14 (VCC), U4.4 (VCC), U4.32 (AVCC), U5.4 (VCC), U5.32 (AVCC), U6.10 (VCC), U6.31 (VCC), U6.61 (VCC), U6.80 (VCC)
5V_USB: C14.1, C33.1, C35.1, C43.1, C44.1, D7.1 (K), D11.2 (A), FB3.2, JP3.1, U4.31 (UVCC)
5V_WALL: C13.1, C15.1, D6.3 (NC), FB2.1, JP1.1, L4.2, R14.1
/PCBMountButtons/FIRST_DIN: D12.2 (A), R15.2, R16.2, R22.1; also elsewhere on the board
AREF: C29.1, C47.1, D15.1 (K), J18.1, J19.1, R37.2, U6.98 (AREF)
BARREL_DETECT: C18.1, R14.2, R50.1, R52.1
BREF: D15.2 (K), J18.3, J19.3, R38.1, U6.86 (PK3)
BTN1a: R10.1, U6.59 (PC6)
BTN1b: R12.1, U5.5 (PC2)
BTN2a: R23.1, U6.55 (PC2)
BTN2b: R24.1, U5.26 (PC4)
BTN3a: R28.1, U6.50 (PD7)
BTN3b: R29.1, U5.25 (PC5)
BTN4a: R31.1, U6.42 (PL7)
BTN4b: R32.1, U5.23 (PC6)
BTN5: U6.38 (PL3); also elsewhere on the board
BTN6: U6.60 (PC7); also elsewhere on the board
BTN7: U6.58 (PC5); also elsewhere on the board
BTN8: U6.54 (PC1); also elsewhere on the board
BTN9: U6.52 (PG1); also elsewhere on the board
BTN10: U6.40 (PL5); also elsewhere on the board
BTN11: U6.7 (PE5); also elsewhere on the board
BTN12: U6.74 (PA4); also elsewhere on the board
BTN13: U6.71 (PA7); also elsewhere on the board
BTN14: U6.57 (PC4); also elsewhere on the board
BTN15: U6.70 (PG2); also elsewhere on the board
BTN16: U6.39 (PL4); also elsewhere on the board
BTN17: U6.36 (PL1); also elsewhere on the board
BTN18: U6.6 (PE4); also elsewhere on the board
BTN19: U6.78 (PA0); also elsewhere on the board
BTN20: U6.75 (PA3); also elsewhere on the board
BTN21: U6.72 (PA6); also elsewhere on the board
BTN22: U6.56 (PC3); also elsewhere on the board
BTN23: U6.51 (PG0); also elsewhere on the board
BTN24: U6.35 (PL0); also elsewhere on the board
BTN25: U6.65 (PJ2); also elsewhere on the board
BTN26: U6.84 (PK5); also elsewhere on the board
BTN27: U6.67 (PJ4); also elsewhere on the board
BTN28: U6.66 (PJ3); also elsewhere on the board
BTN29: U6.76 (PA2); also elsewhere on the board
BTN30: U6.73 (PA5); also elsewhere on the board
BTN31: U6.53 (PC0); also elsewhere on the board
BTN32: U6.37 (PL2); also elsewhere on the board
BTN33: U6.82 (PK7); also elsewhere on the board
BTN34: U6.85 (PK4); also elsewhere on the board
BTN35: U6.68 (PJ5); also elsewhere on the board
BTN36: U6.64 (PJ1); also elsewhere on the board
BTN37: U6.27 (PH7); also elsewhere on the board
BTN38: U6.12 (PH0); also elsewhere on the board
BTN39: U6.77 (PA1); also elsewhere on the board
BTN40: U6.41 (PL6); also elsewhere on the board
BTN41: U6.83 (PK6); also elsewhere on the board
BTN42: U6.89 (PK0); also elsewhere on the board
BTN43: U6.90 (PF7); also elsewhere on the board
BTN44: U6.5 (PE3); also elsewhere on the board
BTN45: U6.1 (PG5); also elsewhere on the board
BTN46: U6.63 (PJ0); also elsewhere on the board
BTN47: U6.15 (PH3); also elsewhere on the board
BTN48: U6.93 (PF4); also elsewhere on the board
BTN49: U6.91 (PF6); also elsewhere on the board
BTN50: U6.92 (PF5); also elsewhere on the board
BTN51: U6.24 (PB5); also elsewhere on the board
BTN52: U6.23 (PB4); also elsewhere on the board
BTN53: U6.17 (PH5); also elsewhere on the board
BTN54: U6.16 (PH4); also elsewhere on the board
BTN55: U6.96 (PF1); also elsewhere on the board
BTN56: U6.94 (PF3); also elsewhere on the board
BTN57: U6.25 (PB6); also elsewhere on the board
BTN58: U6.26 (PB7); also elsewhere on the board
BTN59: U6.18 (PH6); also elsewhere on the board
BTN60: U6.19 (PB0); also elsewhere on the board
BTN61: U6.95 (PF2); also elsewhere on the board
BTN62: U6.8 (PE6); also elsewhere on the board
BTN63: U6.9 (PE7); also elsewhere on the board
BTN64: U6.28 (PG3); also elsewhere on the board
BTN65: U6.29 (PG4); also elsewhere on the board
BTNX-1: J4.1, U6.43 (PD0)
BTNX-2: J5.1, U6.44 (PD1)
BTNX-3: J6.1, U6.47 (PD4)
BTNX-4: J10.1, U6.48 (PD5)
BTNX-5: J11.1, U6.49 (PD6)
BTNX-6: J7.1, U6.79 (PJ7)
BTNX-7: J8.1, U6.69 (PJ6)
BTNX-8: J9.1, U6.4 (PE2)
D+: D4.2 (K), R5.1, U4.29 (D+)
D-: D4.1 (K), R6.1, U4.30 (D-)
GND: C1.2, C2.2, C5.2, C7.2, C10.2, C11.2, C13.2, C14.2, C15.2, C17.2, C18.2, C19.2, C23.2, C30.2, C31.2, C32.2, C33.2, C35.2, C36.2, C37.2, C38.2, C39.2, C40.2, C41.2, C42.2, C43.2, C44.2, C45.2, C46.2, C47.2, C48.2, C49.2, C50.2, D1.1 (K), D1.2 (A), D2.3 (A), D4.3 (A), D5.2 (A), D6.1 (K), D6.2 (A), D7.2 (A), D9.3 (A), D13.3 (A), D14.3 (A), D15.3 (A), FB1.1, J1.2, J1.3, J3.4 (GND), J4.2, J5.2, J6.2, J7.2, J8.2, J9.2, J10.2, J11.2, J12.2, J13.2, J14.2, J15.2, J15.S1 (SHIELD), J15.S2 (SHIELD), J16.2, J17.6, J20.6, J21.6, JP5.2, Q2.1 (S), Q2.4 (S), Q3.4 (S), R22.2, R33.2, R34.2, R41.2, R44.2, R45.2, U1.5 (GND), U3.5, U3.7 (GND), U3.9, U3.11, U3.13, U4.3 (GND), U4.28 (UGND), U4.33 (GND), U5.3 (GND), U5.28 (UGND), U5.33 (GND), Y1.2, Y2.2, Y3.2; also elsewhere on the board
GNDA: C29.2, JP4.1, R35.2, R36.2, R38.2
M8RXD: R51.1, U4.9 (PD3)
M8TXD: R53.1, U4.8 (PD2)
MCU1-MCU3_GPIO: U5.11 (PD5), U6.14 (PH2)
MCU1-MCU3_TX: U5.8 (PD2), U6.13 (PH1)
MCU1_MISO: J21.1, U6.22 (PB3)
MCU1_RST: C45.1, D18.2 (A), J21.5, JP2.2, Q3.3 (D), R48.1, U6.30 (~RESET)
MCU1_SCK: J21.3, U6.20 (PB1)
MCU2_LED_CTRL: R16.1, R42.1, R43.1
MCU2_MISO2: J17.1, U4.17 (PB3)
MCU2_MOSI2: J17.4, Q2.3 (D), R42.2, U4.16 (PB2)
MCU2_RST: C30.1, D16.2 (A), J17.5, Q2.6 (D), R39.2, U4.24 (PC1/~RESET)
MCU2_SCK2: J17.3, U4.15 (PB1)
MCU3_LED_CTRL: R15.1, R47.1, R49.1
MCU3_MISO3: J20.1, U5.17 (PB3)
MCU3_MOSI3: J20.4, R47.2, U5.16 (PB2)
MCU3_RST: C32.1, D17.2 (A), J20.5, R40.2, U5.24 (PC1/~RESET)
MCU3_SCK3: J20.3, U5.15 (PB1)
MCU_MOSI: J21.4, U6.21 (PB2)
MIDI-OUT: U3.1, U6.46 (PD3)
unnamed: C1.1, J2.S1 (SHIELD), J2.S2 (SHIELD)
unnamed: C2.1, J2.2
unnamed: C5.1, C7.1, D1.3 (NC), F1.1, L1.2
unnamed: C10.1, D5.1 (K), F2.1, L2.2
unnamed: C31.1, U4.27 (UCAP)
unnamed: C34.1, R41.1, U4.13 (~HWB~/PD7)
unnamed: C34.2, JP2.1
unnamed: C38.1, U5.27 (UCAP)
unnamed: C46.1, R50.2, U5.10 (PD4)
unnamed: C50.1, R52.2, U6.97 (PF0)
unnamed: D2.1 (K), R3.1, R6.2
unnamed: D2.2 (K), R2.1, R5.2
unnamed: D3.1 (K), R1.2, R4.2
unnamed: D3.2 (K), R4.1, U1.2 (A)
unnamed: D3.3 (A), J2.5, U1.3 (C)
unnamed: D9.1 (K), R11.1, R21.1
unnamed: D9.2 (K), J15.5, R21.2
unnamed: D10.2 (A), L4.1
unnamed: D13.1 (K), J15.4, R26.2
unnamed: D13.2 (K), R25.2, R26.1
unnamed: F1.2, J1.1
unnamed: F2.2, J3.1 (VBUS)
unnamed: FB1.2, J3.5 (Shield)
unnamed: FB2.2, L1.1
unnamed: FB3.1, L2.1
unnamed: J2.4, R1.1
unnamed: J3.2 (D-), R3.2
unnamed: J3.3 (D+), R2.2
unnamed: J12.1, R9.2, R10.2, R12.2
unnamed: J13.1, R18.2, R23.2, R24.2
unnamed: J14.1, R27.2, R28.2, R29.2
unnamed: J16.1, R30.2, R31.2, R32.2
unnamed: JP3.2, TP18.1, U5.31 (UVCC)
unnamed: JP4.2, JP5.1, U6.11 (GND), U6.32 (GND), U6.62 (GND), U6.81 (GND), U6.99 (GND)
unnamed: Q3.1 (S), TP20.1
unnamed: Q3.2 (G), TP17.1
unnamed: Q3.6 (D), TP19.1
unnamed: R8.1, U1.6 (VO)
unnamed: R11.2, U3.4
unnamed: R43.2, U4.21 (PB7)
unnamed: R45.1, R46.2, U5.13 (~HWB~/PD7)
unnamed: R49.2, U5.21 (PB7)
unnamed: R51.2, U6.2 (PE0)
unnamed: R53.2, U6.3 (PE1)
unnamed: TP1.1, U4.14 (PB0)
unnamed: TP2.1, U4.18 (PB4)
unnamed: TP3.1, U4.19 (PB5)
unnamed: TP4.1, U4.20 (PB6)
unnamed: TP5.1, U4.5 (PC2)
unnamed: TP6.1, U4.26 (PC4)
unnamed: TP7.1, U4.25 (PC5)
unnamed: TP8.1, U4.23 (PC6)
unnamed: TP9.1, U4.22 (PC7)
unnamed: TP10.1, U4.6 (PD0)
unnamed: TP11.1, U4.7 (PD1)
unnamed: TP12.1, U4.10 (PD4)
unnamed: TP13.1, U4.11 (PD5)
unnamed: TP14.1, U4.12 (PD6)
unnamed: TP15.1, U5.29 (D+)
unnamed: TP16.1, U5.30 (D-)
unnamed: TP21.1, U5.14 (PB0)
unnamed: TP22.1, U5.18 (PB4)
unnamed: TP23.1, U5.19 (PB5)
unnamed: TP24.1, U5.20 (PB6)
unnamed: TP25.1, U5.22 (PC7)
unnamed: TP26.1, U5.12 (PD6)
unnamed: U3.2, U3.3
unnamed: U4.1 (XTAL1), Y1.1
unnamed: U4.2 (PC0/XTAL2), Y1.3
unnamed: U5.1 (XTAL1), Y2.1
unnamed: U5.2 (PC0/XTAL2), Y2.3
unnamed: U6.33 (XTAL2), Y3.3
unnamed: U6.34 (XTAL1), Y3.1
PROG_CTRL_1: Q2.2 (G), R33.1, U5.7 (PD1)
PROG_CTRL_2: Q2.5 (G), R34.1, U5.6 (PD0)
RST_2560: Q3.5 (G), R44.1, U5.9 (PD3)
VLED: D12.1 (K), JP1.2; also elsewhere on the board
softpot-1: D14.2 (K), J18.2, R35.1, U6.88 (PK1)
softpot-2: D14.1 (K), J19.2, R36.1, U6.87 (PK2)

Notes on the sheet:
SOFTPOTS
USB B Input
Filter and Surge & Reverse Polarity Protection
BARREL POWER DETECT
TODO footprint
Diode OR for MCU Power
ARDUINO INTERFACE MCU (2)
MAIN MCU (1)
QUESTION, NEED BOARD LEVEL DISCRETE LEDS?
ICSP
QUESTION, DO WE NEED RESET BUTTONS ON BOARD?
LED CONTROLLER MCU (3)
QUESTION, ASIDE FROM INPUT/OUTPUT CONNECTORS, WHAT ELSE NEEDS ESD PROTECTION? EVERY BUTTON/GPIO WOULD BE A LOT, MAYBE BEST TO JUST HAVE THE MCUs/ETC ON THE FAR SIDE SO USER CAN'T REACH MOST INPUTS
PROG_CTRL_1 HIGH: Shorts pin 5 - 6 (DFU MODE) PROG_CTRL_2 HIGH: Shorts pin 4 - 6 (ARDUINO MODE) _1 & _2 LOW: USB Midi Mode
USART1 RX
GPIO/USART1_XCK
Choose one or the other to drive the LED, SPI MOSI, or Output Compare
OC0/OC1
512 B RAM 73 LEDs = 73x3 = 219B needed to store all LEDs
5V 8A JACK
Program over ICSP. No Arudino interface, only acts as Meta-Button control (MCU programming mode), & LED driving interface
SPARE
RESET CONTROL
AIN3
Barrel Jack Input
MCU FILTER
Placement Notes: Place MLCC near MCU pins
MIDI OUT
Buttons X1-X12
Buttons 1-4
Buttons 5-61
DNP options in case you want to experiment with running LEDs from Arudino front-end
Diode Protects in case Data present without Power
PCB MOUNT META BUTTONS
NO LEDs Extra HW for sharing button input
NO LEDs
OFF-BOARD BUTTONS
PCB MOUNT RGB BUTTONS
60mA each LED, x61 = 3.7A maximum
TODO: WHY NOT USE A NON-INVERTING BUFFER?

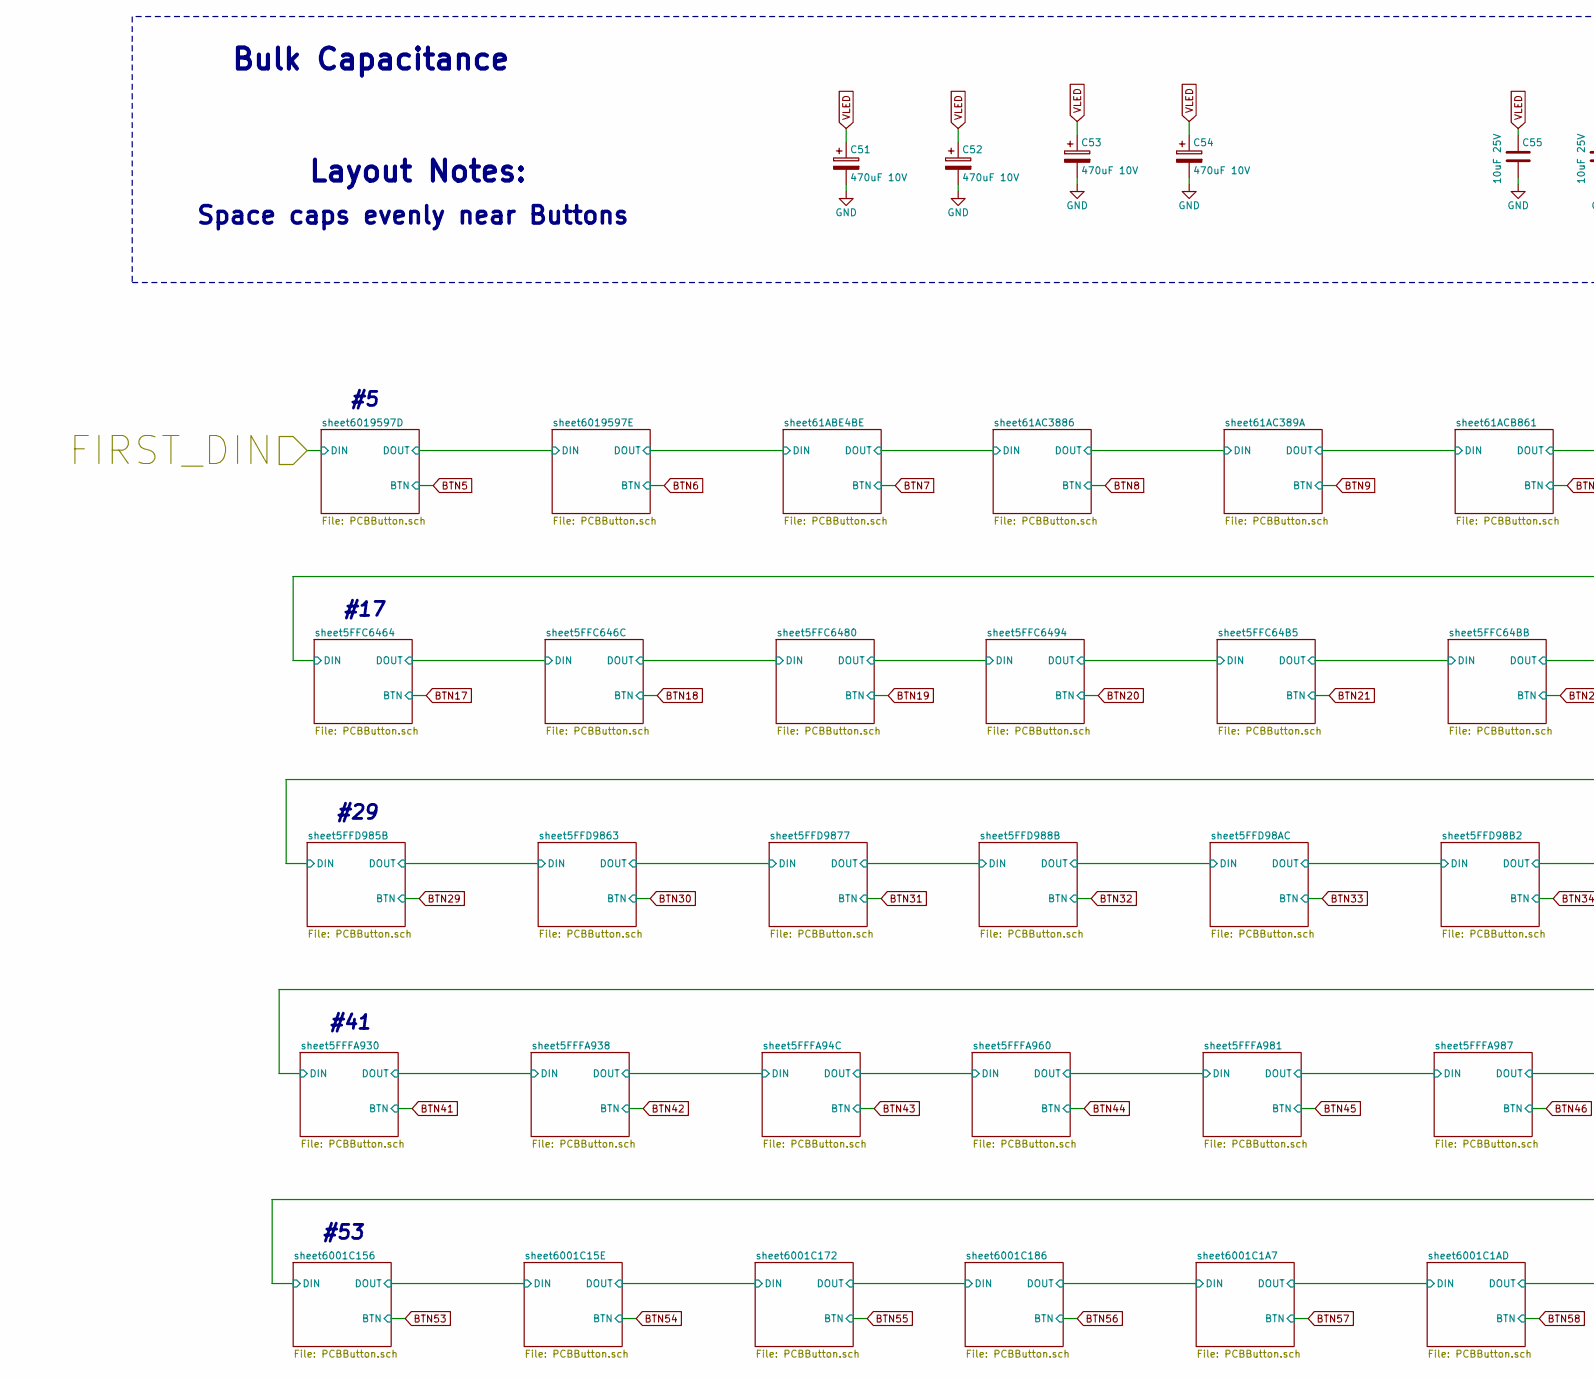
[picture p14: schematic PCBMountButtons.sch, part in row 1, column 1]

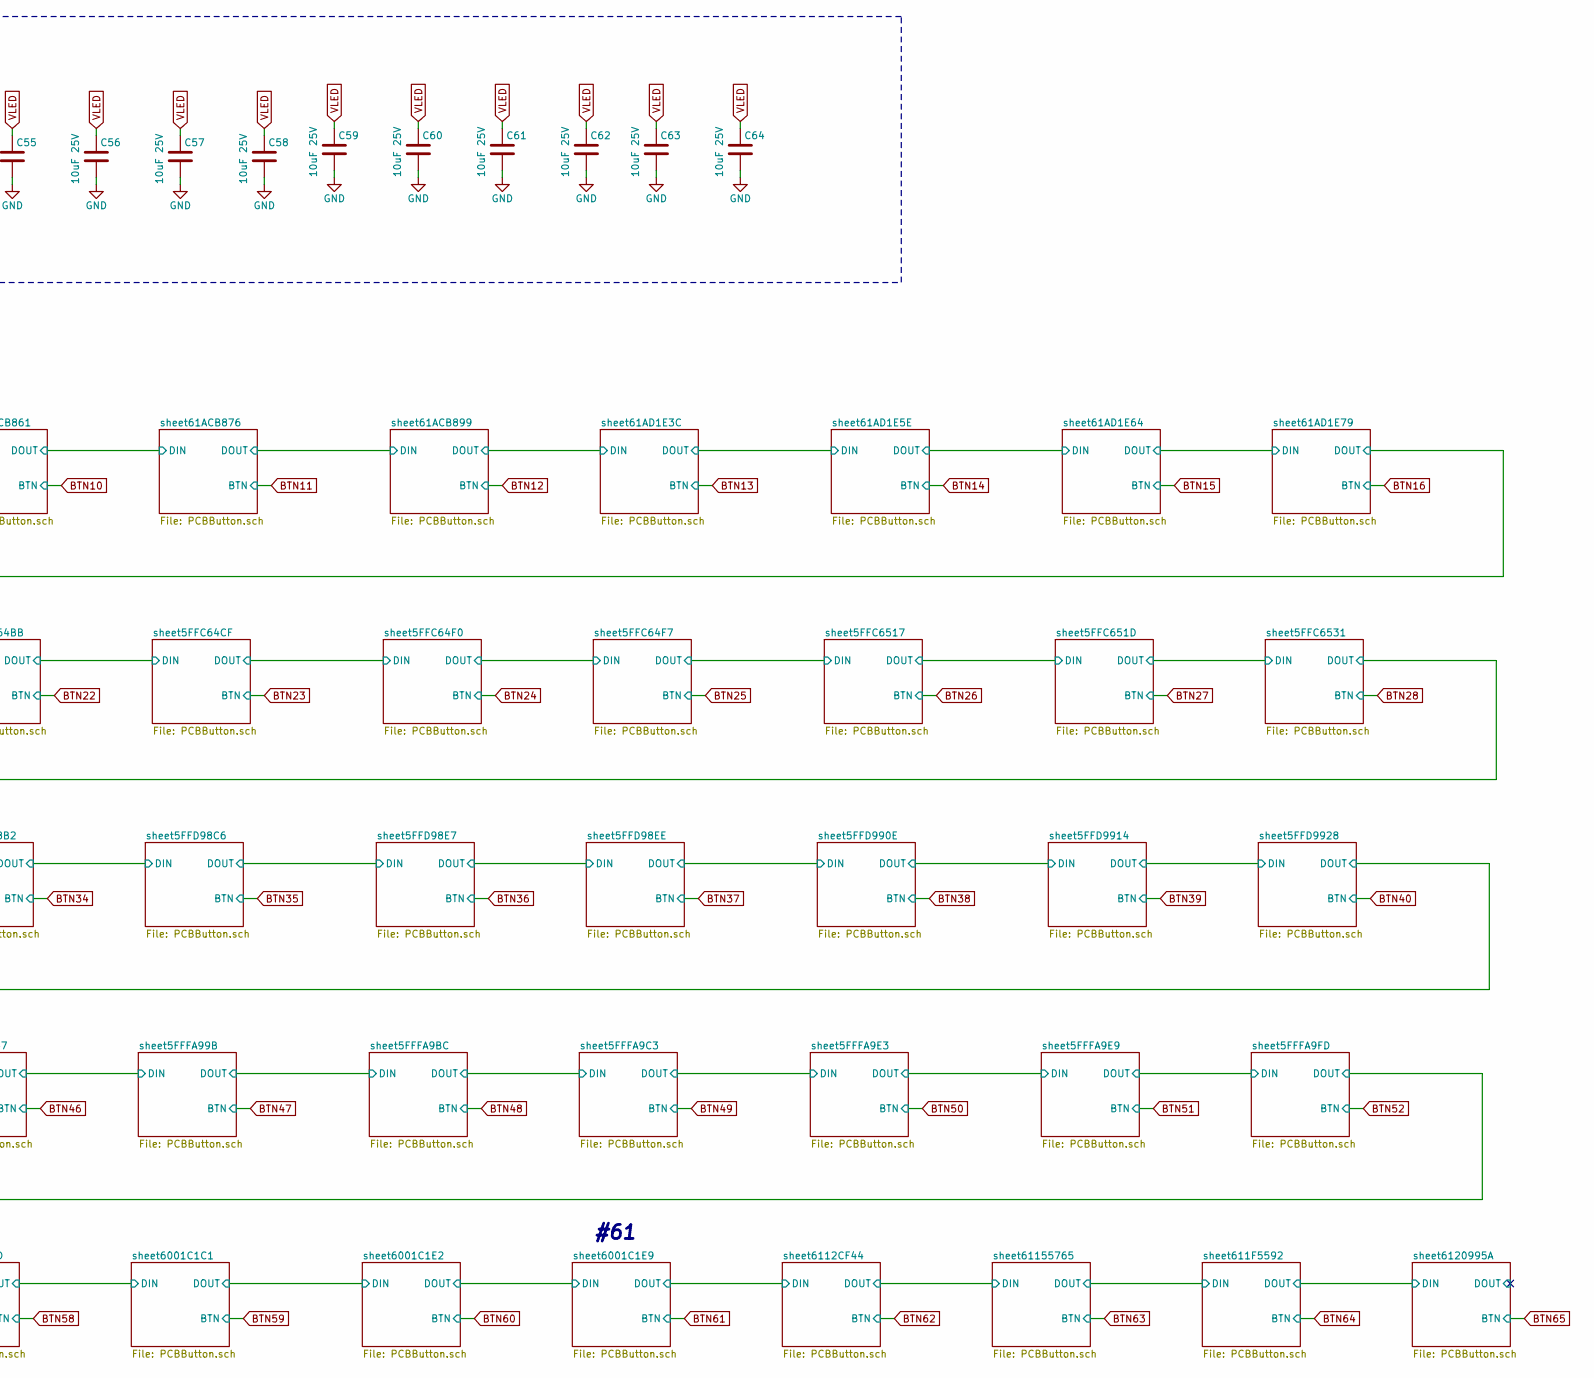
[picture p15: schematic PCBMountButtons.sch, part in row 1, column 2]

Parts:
C51, C52, C53, C54: 470uF 10V; CP_Elec_6.3x7.7
C55, C56, C57, C58, C59, C60, C61, C62, C63, C64: 10uF 25V; C_1206_3216Metric

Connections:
GND: C51.2, C52.2, C53.2, C54.2, C55.2, C56.2, C57.2, C58.2, C59.2, C60.2, C61.2, C62.2, C63.2, C64.2; also elsewhere on the board
VLED: C51.1, C52.1, C53.1, C54.1, C55.1, C56.1, C57.1, C58.1, C59.1, C60.1, C61.1, C62.1, C63.1, C64.1; also elsewhere on the board

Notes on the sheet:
Layout Notes:
Space caps evenly near Buttons
Bulk Capacitance
#17
#29
#41
#53
#61

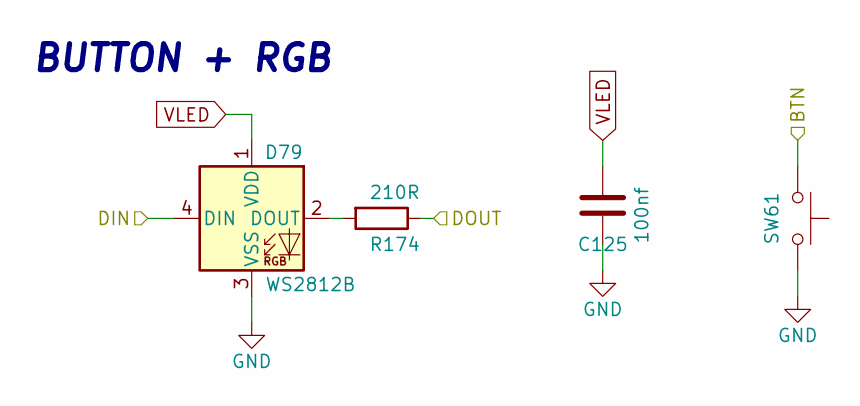
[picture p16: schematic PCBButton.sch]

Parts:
C65: 100nf; C_0603_1608Metric; LCSC C14663
D19: WS2812B; LED_WS2812B_PLCC4_5.0x5.0mm_P3.2mm
R114: 210R; R_0805_2012Metric; LCSC C228630
SW1: SANWA-OBSF24; Sanwa-OBSF24-v2

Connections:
/PCBMountButtons/FIRST_DIN: D19.4 (DIN); also elsewhere on the board
/PCBMountButtons/sheet6019597E/DIN: R114.1; also elsewhere on the board
BTN5: SW1.1; also elsewhere on the board
GND: C65.2, D19.3 (VSS), SW1.2; also elsewhere on the board
unnamed: D19.2 (DOUT), R114.2
VLED: C65.1, D19.1 (VDD); also elsewhere on the board

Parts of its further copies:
C66, C67, C68, C69, C70, C71, C72, C73, C74, C75, C76, C77, C78, C79, C80, C81, C82, C83, C84, C85, C86, C87, C88, C89, C90, C91, C92, C93, C94, C95, C96, C97, C98, C99, C100, C101, C102, C103, C104, C105, C106, C107, C108, C109, C110, C111, C112, C113, C114, C115, C116, C117, C118, C119, C120, C121, C122, C123, C124, C125: 100nf; C_0603_1608Metric; LCSC C14663
D20, D21, D22, D23, D24, D25, D26, D27, D28, D29, D30, D31, D32, D33, D34, D35, D36, D37, D38, D39, D40, D41, D42, D43, D44, D45, D46, D47, D48, D49, D50, D51, D52, D53, D54, D55, D56, D57, D58, D59, D60, D61, D62, D63, D64, D65, D66, D67, D68, D69, D70, D71, D72, D73, D74, D75, D76, D77, D78, D79: WS2812B; LED_WS2812B_PLCC4_5.0x5.0mm_P3.2mm
R115, R116, R117, R118, R119, R120, R121, R122, R123, R124, R125, R126, R127, R128, R129, R130, R131, R132, R133, R134, R135, R136, R137, R138, R139, R140, R141, R142, R143, R144, R145, R146, R147, R148, R149, R150, R151, R152, R153, R154, R155, R156, R157, R158, R159, R160, R161, R162, R163, R164, R165, R166, R167, R168, R169, R170, R171, R172, R173, R174: 210R; R_0805_2012Metric; LCSC C228630
SW2, SW3, SW4, SW5, SW6, SW7, SW8, SW9, SW10, SW11, SW12, SW13, SW14, SW15, SW16, SW17, SW18, SW19, SW20, SW21, SW22, SW23, SW24, SW25, SW26, SW27, SW28, SW29, SW30, SW31, SW32, SW33, SW34, SW35, SW36, SW37, SW38, SW39, SW40, SW41, SW42, SW43, SW44, SW45, SW46, SW47, SW48, SW49, SW50, SW51, SW52, SW53, SW54, SW55, SW56, SW57, SW58, SW59, SW60, SW61: SANWA-OBSF24; Sanwa-OBSF24-v2

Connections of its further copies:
/PCBMountButtons/sheet5FFC64B5/DIN: D35.4 (DIN), R129.1
/PCBMountButtons/sheet5FFC64BB/DIN: D36.4 (DIN), R130.1
/PCBMountButtons/sheet5FFC64CF/DIN: D37.4 (DIN), R131.1
/PCBMountButtons/sheet5FFC64F0/DIN: D38.4 (DIN), R132.1
/PCBMountButtons/sheet5FFC64F7/DIN: D39.4 (DIN), R133.1
/PCBMountButtons/sheet5FFC646C/DIN: D32.4 (DIN), R126.1
/PCBMountButtons/sheet5FFC651D/DIN: D41.4 (DIN), R135.1
/PCBMountButtons/sheet5FFC6464/DIN: D31.4 (DIN), R125.1
/PCBMountButtons/sheet5FFC6480/DIN: D33.4 (DIN), R127.1
/PCBMountButtons/sheet5FFC6494/DIN: D34.4 (DIN), R128.1
/PCBMountButtons/sheet5FFC6517/DIN: D40.4 (DIN), R134.1
/PCBMountButtons/sheet5FFC6531/DIN: D42.4 (DIN), R136.1
/PCBMountButtons/sheet5FFD98AC/DIN: D47.4 (DIN), R141.1
/PCBMountButtons/sheet5FFD98B2/DIN: D48.4 (DIN), R142.1
/PCBMountButtons/sheet5FFD98C6/DIN: D49.4 (DIN), R143.1
/PCBMountButtons/sheet5FFD98E7/DIN: D50.4 (DIN), R144.1
/PCBMountButtons/sheet5FFD98EE/DIN: D51.4 (DIN), R145.1
/PCBMountButtons/sheet5FFD985B/DIN: D43.4 (DIN), R137.1
/PCBMountButtons/sheet5FFD988B/DIN: D46.4 (DIN), R140.1
/PCBMountButtons/sheet5FFD990E/DIN: D52.4 (DIN), R146.1
/PCBMountButtons/sheet5FFD9863/DIN: D44.4 (DIN), R138.1
/PCBMountButtons/sheet5FFD9877/DIN: D45.4 (DIN), R139.1
/PCBMountButtons/sheet5FFD9914/DIN: D53.4 (DIN), R147.1
/PCBMountButtons/sheet5FFD9928/DIN: D54.4 (DIN), R148.1
/PCBMountButtons/sheet5FFFA9BC/DIN: D62.4 (DIN), R156.1
/PCBMountButtons/sheet5FFFA9C3/DIN: D63.4 (DIN), R157.1
/PCBMountButtons/sheet5FFFA9E3/DIN: D64.4 (DIN), R158.1
/PCBMountButtons/sheet5FFFA9E9/DIN: D65.4 (DIN), R159.1
/PCBMountButtons/sheet5FFFA9FD/DIN: D66.4 (DIN), R160.1
/PCBMountButtons/sheet5FFFA94C/DIN: D57.4 (DIN), R151.1
/PCBMountButtons/sheet5FFFA99B/DIN: D61.4 (DIN), R155.1
/PCBMountButtons/sheet5FFFA930/DIN: D55.4 (DIN), R149.1
/PCBMountButtons/sheet5FFFA938/DIN: D56.4 (DIN), R150.1
/PCBMountButtons/sheet5FFFA960/DIN: D58.4 (DIN), R152.1
/PCBMountButtons/sheet5FFFA981/DIN: D59.4 (DIN), R153.1
/PCBMountButtons/sheet5FFFA987/DIN: D60.4 (DIN), R154.1
/PCBMountButtons/sheet61ABE4BE/DIN: D21.4 (DIN), R115.1
/PCBMountButtons/sheet61AC389A/DIN: D23.4 (DIN), R117.1
/PCBMountButtons/sheet61AC3886/DIN: D22.4 (DIN), R116.1
/PCBMountButtons/sheet61ACB861/DIN: D24.4 (DIN), R118.1
/PCBMountButtons/sheet61ACB876/DIN: D25.4 (DIN), R119.1
/PCBMountButtons/sheet61ACB899/DIN: D26.4 (DIN), R120.1
/PCBMountButtons/sheet61AD1E3C/DIN: D27.4 (DIN), R121.1
/PCBMountButtons/sheet61AD1E5E/DIN: D28.4 (DIN), R122.1
/PCBMountButtons/sheet61AD1E64/DIN: D29.4 (DIN), R123.1
/PCBMountButtons/sheet61AD1E79/DIN: D30.4 (DIN), R124.1
/PCBMountButtons/sheet611F5592/DIN: D78.4 (DIN), R172.1
/PCBMountButtons/sheet6001C1A7/DIN: D71.4 (DIN), R165.1
/PCBMountButtons/sheet6001C1AD/DIN: D72.4 (DIN), R166.1
/PCBMountButtons/sheet6001C1C1/DIN: D73.4 (DIN), R167.1
/PCBMountButtons/sheet6001C1E2/DIN: D74.4 (DIN), R168.1
/PCBMountButtons/sheet6001C1E9/DIN: D75.4 (DIN), R169.1
/PCBMountButtons/sheet6001C15E/DIN: D68.4 (DIN), R162.1
/PCBMountButtons/sheet6001C156/DIN: D67.4 (DIN), R161.1
/PCBMountButtons/sheet6001C172/DIN: D69.4 (DIN), R163.1
/PCBMountButtons/sheet6001C186/DIN: D70.4 (DIN), R164.1
/PCBMountButtons/sheet6112CF44/DIN: D76.4 (DIN), R170.1
/PCBMountButtons/sheet6019597E/DIN: D20.4 (DIN); also elsewhere on the board
/PCBMountButtons/sheet6120995A/DIN: D79.4 (DIN), R173.1
/PCBMountButtons/sheet6120995A/DOUT: R174.1
/PCBMountButtons/sheet61155765/DIN: D77.4 (DIN), R171.1
BTN6: SW2.1; also elsewhere on the board
BTN7: SW3.1; also elsewhere on the board
BTN8: SW4.1; also elsewhere on the board
BTN9: SW5.1; also elsewhere on the board
BTN10: SW6.1; also elsewhere on the board
BTN11: SW7.1; also elsewhere on the board
BTN12: SW8.1; also elsewhere on the board
BTN13: SW9.1; also elsewhere on the board
BTN14: SW10.1; also elsewhere on the board
BTN15: SW11.1; also elsewhere on the board
BTN16: SW12.1; also elsewhere on the board
BTN17: SW13.1; also elsewhere on the board
BTN18: SW14.1; also elsewhere on the board
BTN19: SW15.1; also elsewhere on the board
BTN20: SW16.1; also elsewhere on the board
BTN21: SW17.1; also elsewhere on the board
BTN22: SW18.1; also elsewhere on the board
BTN23: SW19.1; also elsewhere on the board
BTN24: SW20.1; also elsewhere on the board
BTN25: SW21.1; also elsewhere on the board
BTN26: SW22.1; also elsewhere on the board
BTN27: SW23.1; also elsewhere on the board
BTN28: SW24.1; also elsewhere on the board
BTN29: SW25.1; also elsewhere on the board
BTN30: SW26.1; also elsewhere on the board
BTN31: SW27.1; also elsewhere on the board
BTN32: SW28.1; also elsewhere on the board
BTN33: SW29.1; also elsewhere on the board
BTN34: SW30.1; also elsewhere on the board
BTN35: SW31.1; also elsewhere on the board
BTN36: SW32.1; also elsewhere on the board
BTN37: SW33.1; also elsewhere on the board
BTN38: SW34.1; also elsewhere on the board
BTN39: SW35.1; also elsewhere on the board
BTN40: SW36.1; also elsewhere on the board
BTN41: SW37.1; also elsewhere on the board
BTN42: SW38.1; also elsewhere on the board
BTN43: SW39.1; also elsewhere on the board
BTN44: SW40.1; also elsewhere on the board
BTN45: SW41.1; also elsewhere on the board
BTN46: SW42.1; also elsewhere on the board
BTN47: SW43.1; also elsewhere on the board
BTN48: SW44.1; also elsewhere on the board
BTN49: SW45.1; also elsewhere on the board
BTN50: SW46.1; also elsewhere on the board
BTN51: SW47.1; also elsewhere on the board
BTN52: SW48.1; also elsewhere on the board
BTN53: SW49.1; also elsewhere on the board
BTN54: SW50.1; also elsewhere on the board
BTN55: SW51.1; also elsewhere on the board
BTN56: SW52.1; also elsewhere on the board
BTN57: SW53.1; also elsewhere on the board
BTN58: SW54.1; also elsewhere on the board
BTN59: SW55.1; also elsewhere on the board
BTN60: SW56.1; also elsewhere on the board
BTN61: SW57.1; also elsewhere on the board
BTN62: SW58.1; also elsewhere on the board
BTN63: SW59.1; also elsewhere on the board
BTN64: SW60.1; also elsewhere on the board
BTN65: SW61.1; also elsewhere on the board
GND: C66.2, C67.2, C68.2, C69.2, C70.2, C71.2, C72.2, C73.2, C74.2, C75.2, C76.2, C77.2, C78.2, C79.2, C80.2, C81.2, C82.2, C83.2, C84.2, C85.2, C86.2, C87.2, C88.2, C89.2, C90.2, C91.2, C92.2, C93.2, C94.2, C95.2, C96.2, C97.2, C98.2, C99.2, C100.2, C101.2, C102.2, C103.2, C104.2, C105.2, C106.2, C107.2, C108.2, C109.2, C110.2, C111.2, C112.2, C113.2, C114.2, C115.2, C116.2, C117.2, C118.2, C119.2, C120.2, C121.2, C122.2, C123.2, C124.2, C125.2, D20.3 (VSS), D21.3 (VSS), D22.3 (VSS), D23.3 (VSS), D24.3 (VSS), D25.3 (VSS), D26.3 (VSS), D27.3 (VSS), D28.3 (VSS), D29.3 (VSS), D30.3 (VSS), D31.3 (VSS), D32.3 (VSS), D33.3 (VSS), D34.3 (VSS), D35.3 (VSS), D36.3 (VSS), D37.3 (VSS), D38.3 (VSS), D39.3 (VSS), D40.3 (VSS), D41.3 (VSS), D42.3 (VSS), D43.3 (VSS), D44.3 (VSS), D45.3 (VSS), D46.3 (VSS), D47.3 (VSS), D48.3 (VSS), D49.3 (VSS), D50.3 (VSS), D51.3 (VSS), D52.3 (VSS), D53.3 (VSS), D54.3 (VSS), D55.3 (VSS), D56.3 (VSS), D57.3 (VSS), D58.3 (VSS), D59.3 (VSS), D60.3 (VSS), D61.3 (VSS), D62.3 (VSS), D63.3 (VSS), D64.3 (VSS), D65.3 (VSS), D66.3 (VSS), D67.3 (VSS), D68.3 (VSS), D69.3 (VSS), D70.3 (VSS), D71.3 (VSS), D72.3 (VSS), D73.3 (VSS), D74.3 (VSS), D75.3 (VSS), D76.3 (VSS), D77.3 (VSS), D78.3 (VSS), D79.3 (VSS), SW2.2, SW3.2, SW4.2, SW5.2, SW6.2, SW7.2, SW8.2, SW9.2, SW10.2, SW11.2, SW12.2, SW13.2, SW14.2, SW15.2, SW16.2, SW17.2, SW18.2, SW19.2, SW20.2, SW21.2, SW22.2, SW23.2, SW24.2, SW25.2, SW26.2, SW27.2, SW28.2, SW29.2, SW30.2, SW31.2, SW32.2, SW33.2, SW34.2, SW35.2, SW36.2, SW37.2, SW38.2, SW39.2, SW40.2, SW41.2, SW42.2, SW43.2, SW44.2, SW45.2, SW46.2, SW47.2, SW48.2, SW49.2, SW50.2, SW51.2, SW52.2, SW53.2, SW54.2, SW55.2, SW56.2, SW57.2, SW58.2, SW59.2, SW60.2, SW61.2; also elsewhere on the board
unnamed: D20.2 (DOUT), R115.2
unnamed: D21.2 (DOUT), R116.2
unnamed: D22.2 (DOUT), R117.2
unnamed: D23.2 (DOUT), R118.2
unnamed: D24.2 (DOUT), R119.2
unnamed: D25.2 (DOUT), R120.2
unnamed: D26.2 (DOUT), R121.2
unnamed: D27.2 (DOUT), R122.2
unnamed: D28.2 (DOUT), R123.2
unnamed: D29.2 (DOUT), R124.2
unnamed: D30.2 (DOUT), R125.2
unnamed: D31.2 (DOUT), R126.2
unnamed: D32.2 (DOUT), R127.2
unnamed: D33.2 (DOUT), R128.2
unnamed: D34.2 (DOUT), R129.2
unnamed: D35.2 (DOUT), R130.2
unnamed: D36.2 (DOUT), R131.2
unnamed: D37.2 (DOUT), R132.2
unnamed: D38.2 (DOUT), R133.2
unnamed: D39.2 (DOUT), R134.2
unnamed: D40.2 (DOUT), R135.2
unnamed: D41.2 (DOUT), R136.2
unnamed: D42.2 (DOUT), R137.2
unnamed: D43.2 (DOUT), R138.2
unnamed: D44.2 (DOUT), R139.2
unnamed: D45.2 (DOUT), R140.2
unnamed: D46.2 (DOUT), R141.2
unnamed: D47.2 (DOUT), R142.2
unnamed: D48.2 (DOUT), R143.2
unnamed: D49.2 (DOUT), R144.2
unnamed: D50.2 (DOUT), R145.2
unnamed: D51.2 (DOUT), R146.2
unnamed: D52.2 (DOUT), R147.2
unnamed: D53.2 (DOUT), R148.2
unnamed: D54.2 (DOUT), R149.2
unnamed: D55.2 (DOUT), R150.2
unnamed: D56.2 (DOUT), R151.2
unnamed: D57.2 (DOUT), R152.2
unnamed: D58.2 (DOUT), R153.2
unnamed: D59.2 (DOUT), R154.2
unnamed: D60.2 (DOUT), R155.2
unnamed: D61.2 (DOUT), R156.2
unnamed: D62.2 (DOUT), R157.2
unnamed: D63.2 (DOUT), R158.2
unnamed: D64.2 (DOUT), R159.2
unnamed: D65.2 (DOUT), R160.2
unnamed: D66.2 (DOUT), R161.2
unnamed: D67.2 (DOUT), R162.2
unnamed: D68.2 (DOUT), R163.2
unnamed: D69.2 (DOUT), R164.2
unnamed: D70.2 (DOUT), R165.2
unnamed: D71.2 (DOUT), R166.2
unnamed: D72.2 (DOUT), R167.2
unnamed: D73.2 (DOUT), R168.2
unnamed: D74.2 (DOUT), R169.2
unnamed: D75.2 (DOUT), R170.2
unnamed: D76.2 (DOUT), R171.2
unnamed: D77.2 (DOUT), R172.2
unnamed: D78.2 (DOUT), R173.2
unnamed: D79.2 (DOUT), R174.2
VLED: C66.1, C67.1, C68.1, C69.1, C70.1, C71.1, C72.1, C73.1, C74.1, C75.1, C76.1, C77.1, C78.1, C79.1, C80.1, C81.1, C82.1, C83.1, C84.1, C85.1, C86.1, C87.1, C88.1, C89.1, C90.1, C91.1, C92.1, C93.1, C94.1, C95.1, C96.1, C97.1, C98.1, C99.1, C100.1, C101.1, C102.1, C103.1, C104.1, C105.1, C106.1, C107.1, C108.1, C109.1, C110.1, C111.1, C112.1, C113.1, C114.1, C115.1, C116.1, C117.1, C118.1, C119.1, C120.1, C121.1, C122.1, C123.1, C124.1, C125.1, D20.1 (VDD), D21.1 (VDD), D22.1 (VDD), D23.1 (VDD), D24.1 (VDD), D25.1 (VDD), D26.1 (VDD), D27.1 (VDD), D28.1 (VDD), D29.1 (VDD), D30.1 (VDD), D31.1 (VDD), D32.1 (VDD), D33.1 (VDD), D34.1 (VDD), D35.1 (VDD), D36.1 (VDD), D37.1 (VDD), D38.1 (VDD), D39.1 (VDD), D40.1 (VDD), D41.1 (VDD), D42.1 (VDD), D43.1 (VDD), D44.1 (VDD), D45.1 (VDD), D46.1 (VDD), D47.1 (VDD), D48.1 (VDD), D49.1 (VDD), D50.1 (VDD), D51.1 (VDD), D52.1 (VDD), D53.1 (VDD), D54.1 (VDD), D55.1 (VDD), D56.1 (VDD), D57.1 (VDD), D58.1 (VDD), D59.1 (VDD), D60.1 (VDD), D61.1 (VDD), D62.1 (VDD), D63.1 (VDD), D64.1 (VDD), D65.1 (VDD), D66.1 (VDD), D67.1 (VDD), D68.1 (VDD), D69.1 (VDD), D70.1 (VDD), D71.1 (VDD), D72.1 (VDD), D73.1 (VDD), D74.1 (VDD), D75.1 (VDD), D76.1 (VDD), D77.1 (VDD), D78.1 (VDD), D79.1 (VDD); also elsewhere on the board

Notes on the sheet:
BUTTON + RGB

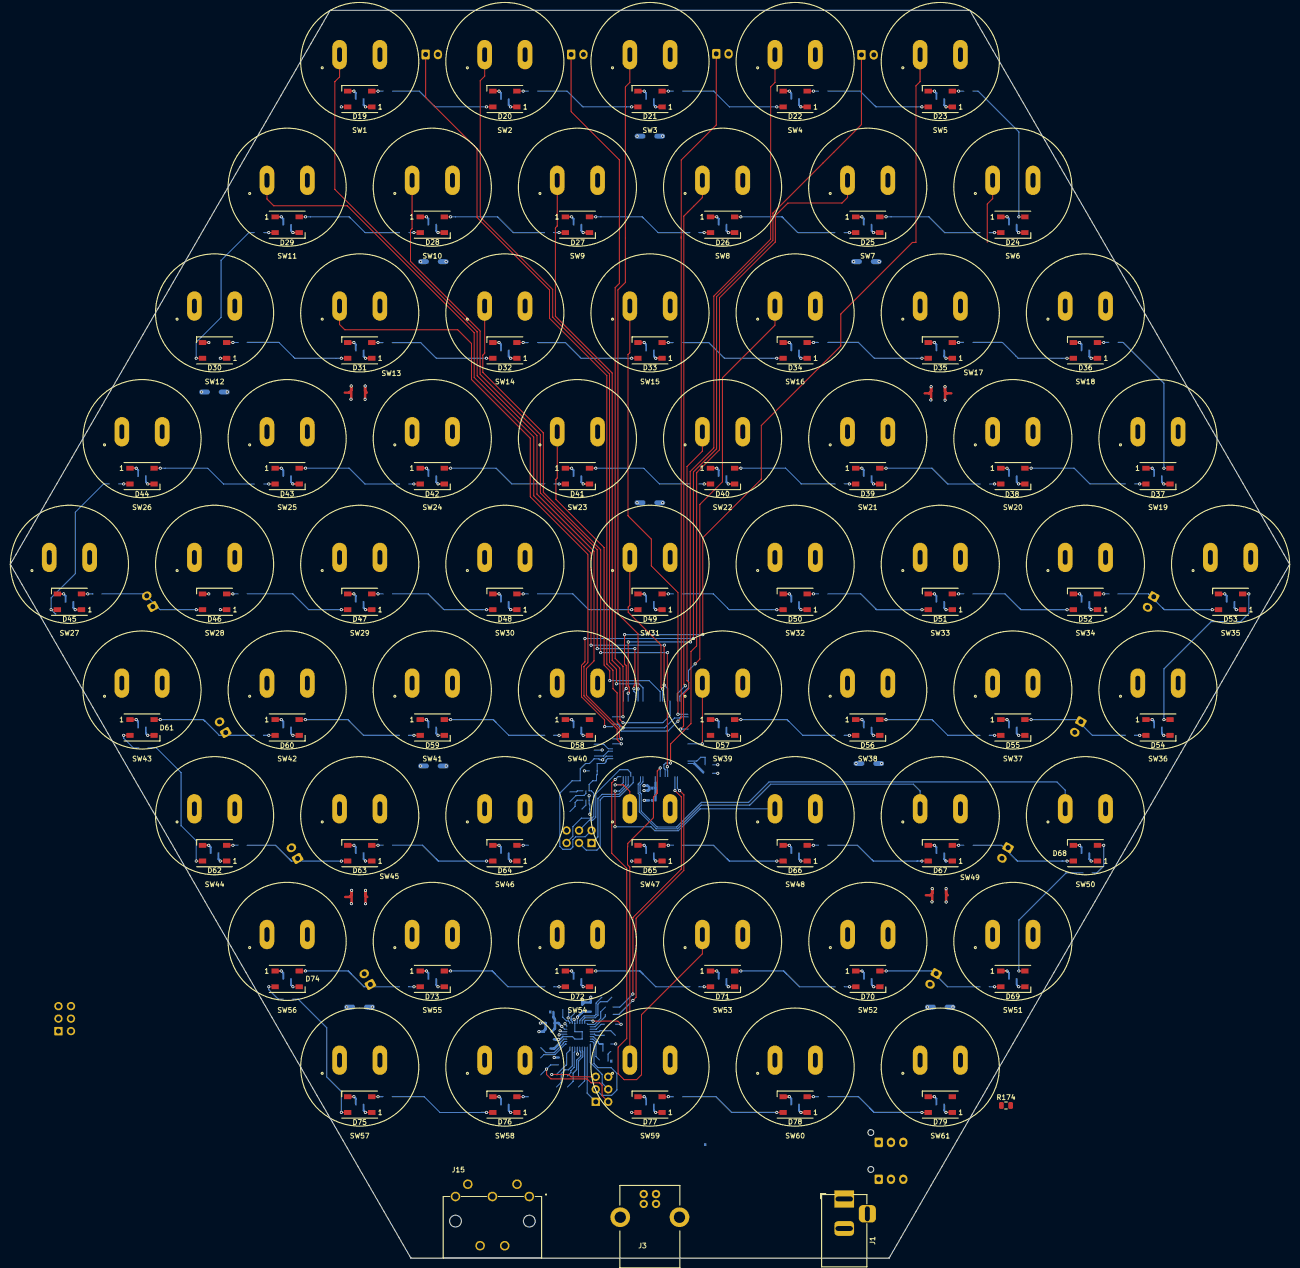
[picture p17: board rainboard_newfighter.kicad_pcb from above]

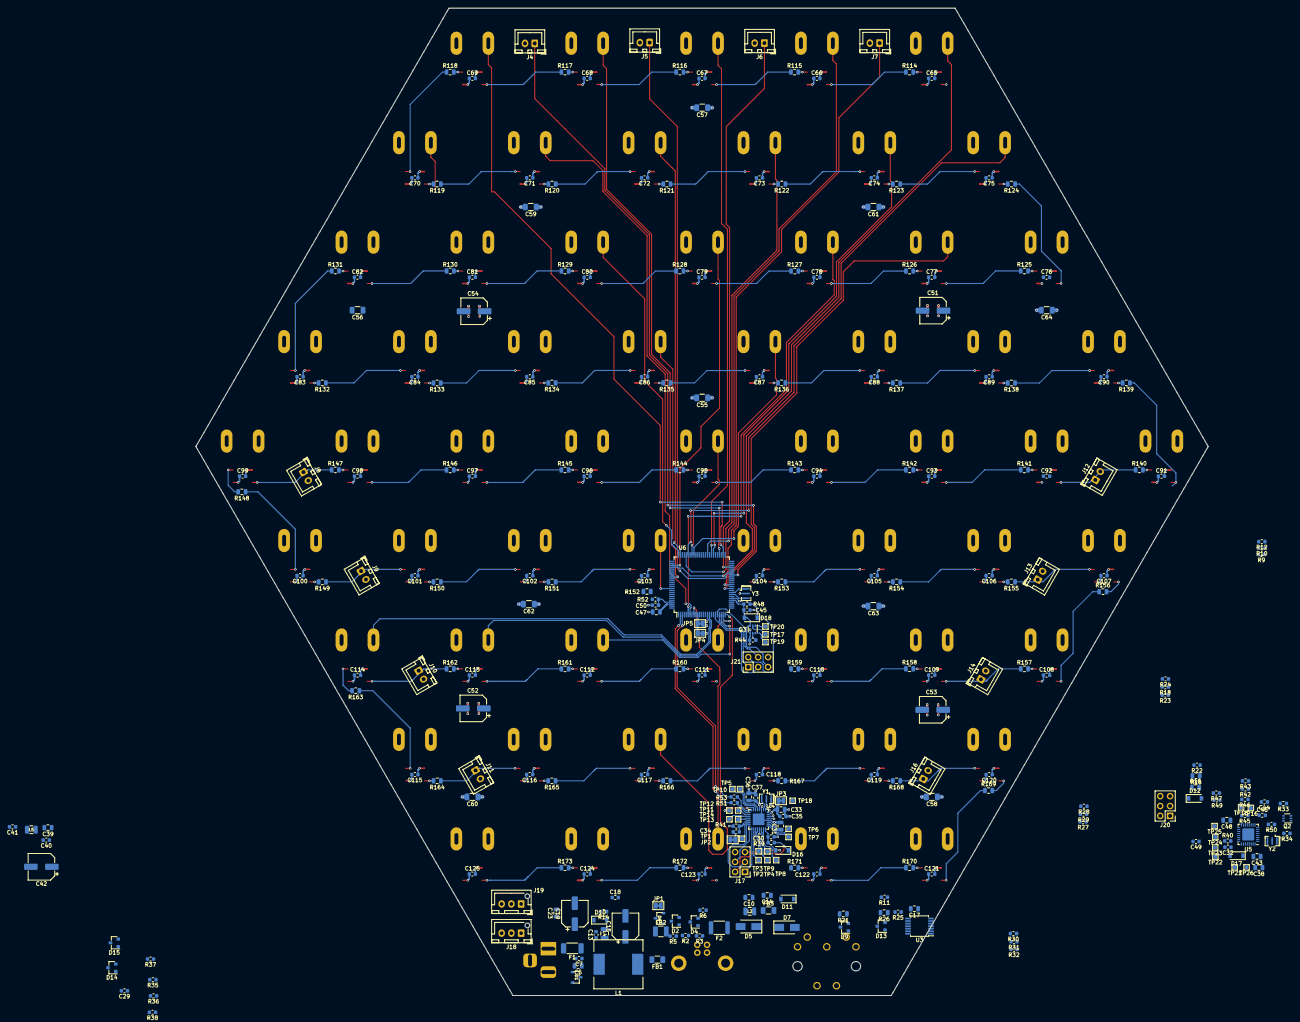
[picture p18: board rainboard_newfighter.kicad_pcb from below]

Board: 4 copper layers, 260.0 x 253.6 mm, 420 parts (294 on the bottom side), 301 nets.

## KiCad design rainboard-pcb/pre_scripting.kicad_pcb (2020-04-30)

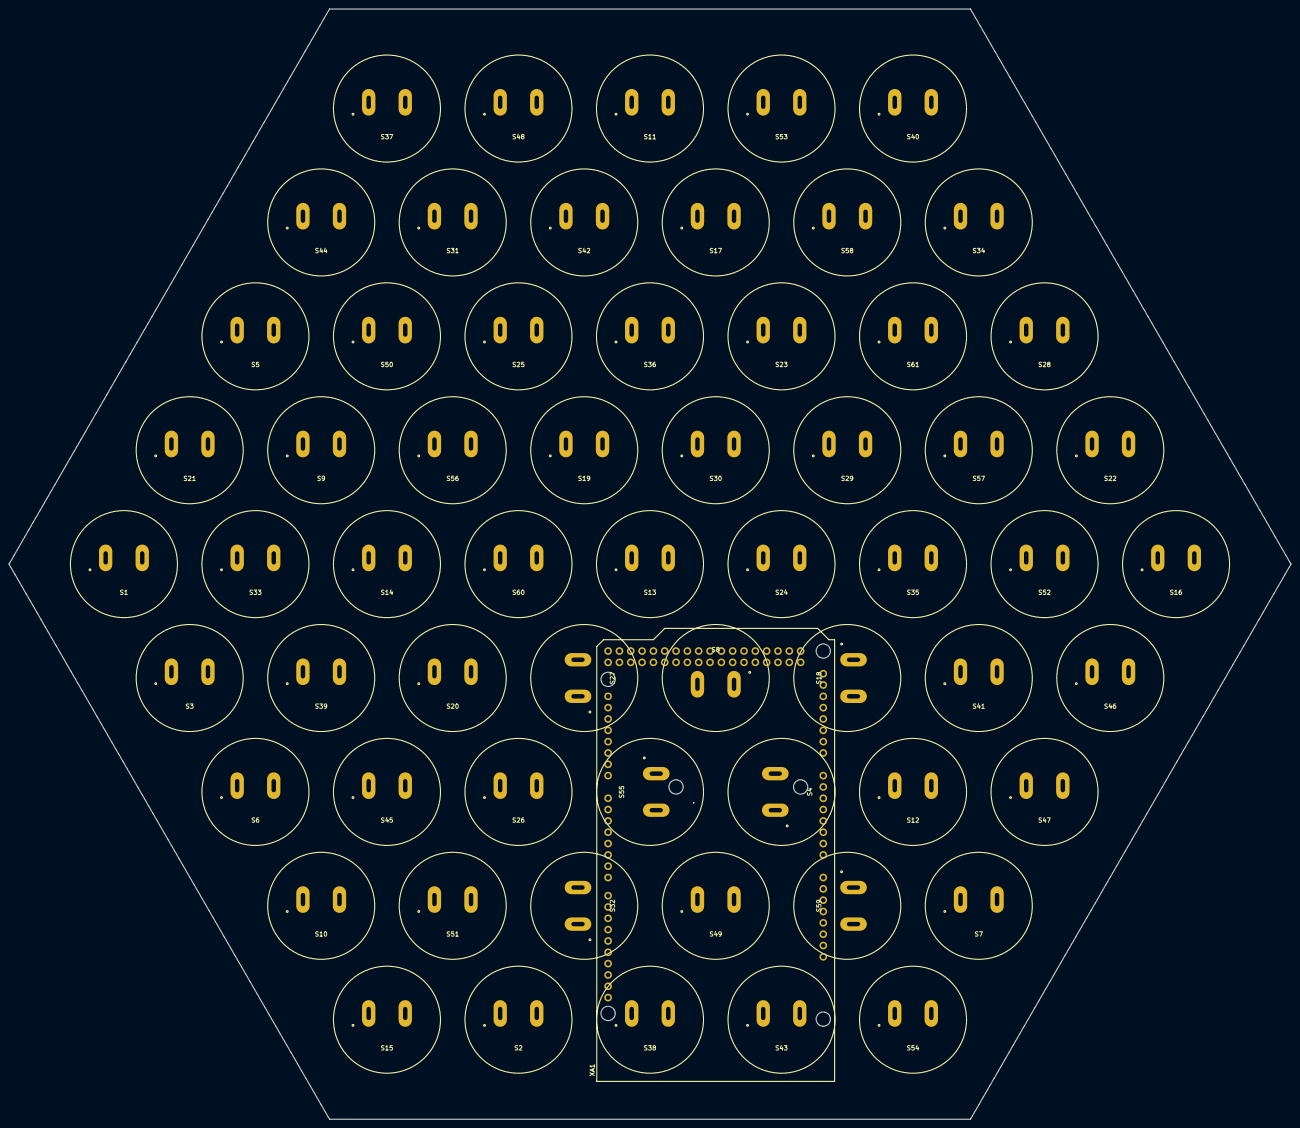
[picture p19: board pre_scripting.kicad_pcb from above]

Board: 2 copper layers, 287.5 x 249.0 mm, 62 parts (0 on the bottom side), 62 nets, no tracks yet.

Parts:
S1, S2, S3, S4, S5, S6, S7, S8, S9, S10, S11, S12, S13, S14, S15, S16, S17, S18, S19, S20, S21, S22, S23, S24, S25, S26, S27, S28, S29, S30, S31, S32, S33, S34, S35, S36, S37, S38, S39, S40, S41, S42, S43, S44, S45, S46, S47, S48, S49, S50, S51, S52, S53, S54, S55, S56, S57, S58, S59, S60, S61: SANWA-OBSF24; Sanwa-OBSF24
XA1: Arduino_Mega2560_Shield

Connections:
Earth: S1.1, S2.1, S3.1, S4.1, S5.1, S6.1, S7.1, S8.1, S9.1, S10.1, S11.1, S12.1, S13.1, S14.1, S15.1, S16.1, S17.1, S18.1, S19.1, S20.1, S21.1, S22.1, S23.1, S24.1, S25.1, S26.1, S27.1, S28.1, S29.1, S30.1, S31.1, S32.1, S33.1, S34.1, S35.1, S36.1, S37.1, S38.1, S39.1, S40.1, S41.1, S42.1, S43.1, S44.1, S45.1, S46.1, S47.1, S48.1, S49.1, S50.1, S51.1, S52.1, S53.1, S54.1, S55.1, S56.1, S57.1, S58.1, S59.1, S60.1, S61.1, XA1.GND1, XA1.GND2, XA1.GND3, XA1.GND5, XA1.GND6
button-01: S1.2, XA1.D1, XA1.SCL, XA1.SDA
button-02: S2.2, XA1.D2
button-03: S3.2, XA1.D3
button-04: S4.2, XA1.D4
button-05: S5.2, XA1.D5
button-06: S6.2, XA1.D6
button-07: S7.2, XA1.D7
button-08: S8.2, XA1.D8
button-09: S9.2, XA1.D9
button-10: S10.2, XA1.D10
button-11: S11.2, XA1.D11
button-12: S12.2, XA1.D12
button-13: S13.2, XA1.D13
button-14: S14.2, XA1.D14
button-15: S15.2, XA1.D15
button-16: S16.2, XA1.D16
button-17: S17.2, XA1.D17
button-18: S18.2, XA1.D18
button-19: S19.2, XA1.D19
button-20: S20.2, XA1.D20
button-21: S21.2, XA1.D21
button-22: S22.2, XA1.D22
button-23: S23.2, XA1.D23
button-24: S24.2, XA1.D24
button-25: S25.2, XA1.D25
button-26: S26.2, XA1.D26
button-27: S27.2, XA1.D27
button-28: S28.2, XA1.D28
button-29: S29.2, XA1.D29
button-30: S30.2, XA1.D30
button-31: S31.2, XA1.D31
button-32: S32.2, XA1.D32
button-33: S33.2, XA1.D33
button-34: S34.2, XA1.D34
button-35: S35.2, XA1.D35
button-36: S36.2, XA1.D36
button-37: S37.2, XA1.D37
button-38: S38.2, XA1.D38
button-39: S39.2, XA1.D39
button-40: S40.2, XA1.D40
button-41: S41.2, XA1.D41
button-42: S42.2, XA1.D42
button-43: S43.2, XA1.D43
button-44: S44.2, XA1.D44
button-45: S45.2, XA1.D45
button-46: S46.2, XA1.D46
button-47: S47.2, XA1.D47
button-48: S48.2, XA1.D48
button-49: S49.2, XA1.D49
button-50: S50.2, XA1.D50
button-51: S51.2, XA1.D51
button-52: S52.2, XA1.D52
button-53: S53.2, XA1.D53
button-54: S54.2, XA1.A0
button-55: S55.2, XA1.A1
button-56: S56.2, XA1.A2
button-57: S57.2, XA1.A3
button-58: S58.2, XA1.A4
button-59: S59.2, XA1.A5
button-60: S60.2, XA1.A6
button-61: S61.2, XA1.A7

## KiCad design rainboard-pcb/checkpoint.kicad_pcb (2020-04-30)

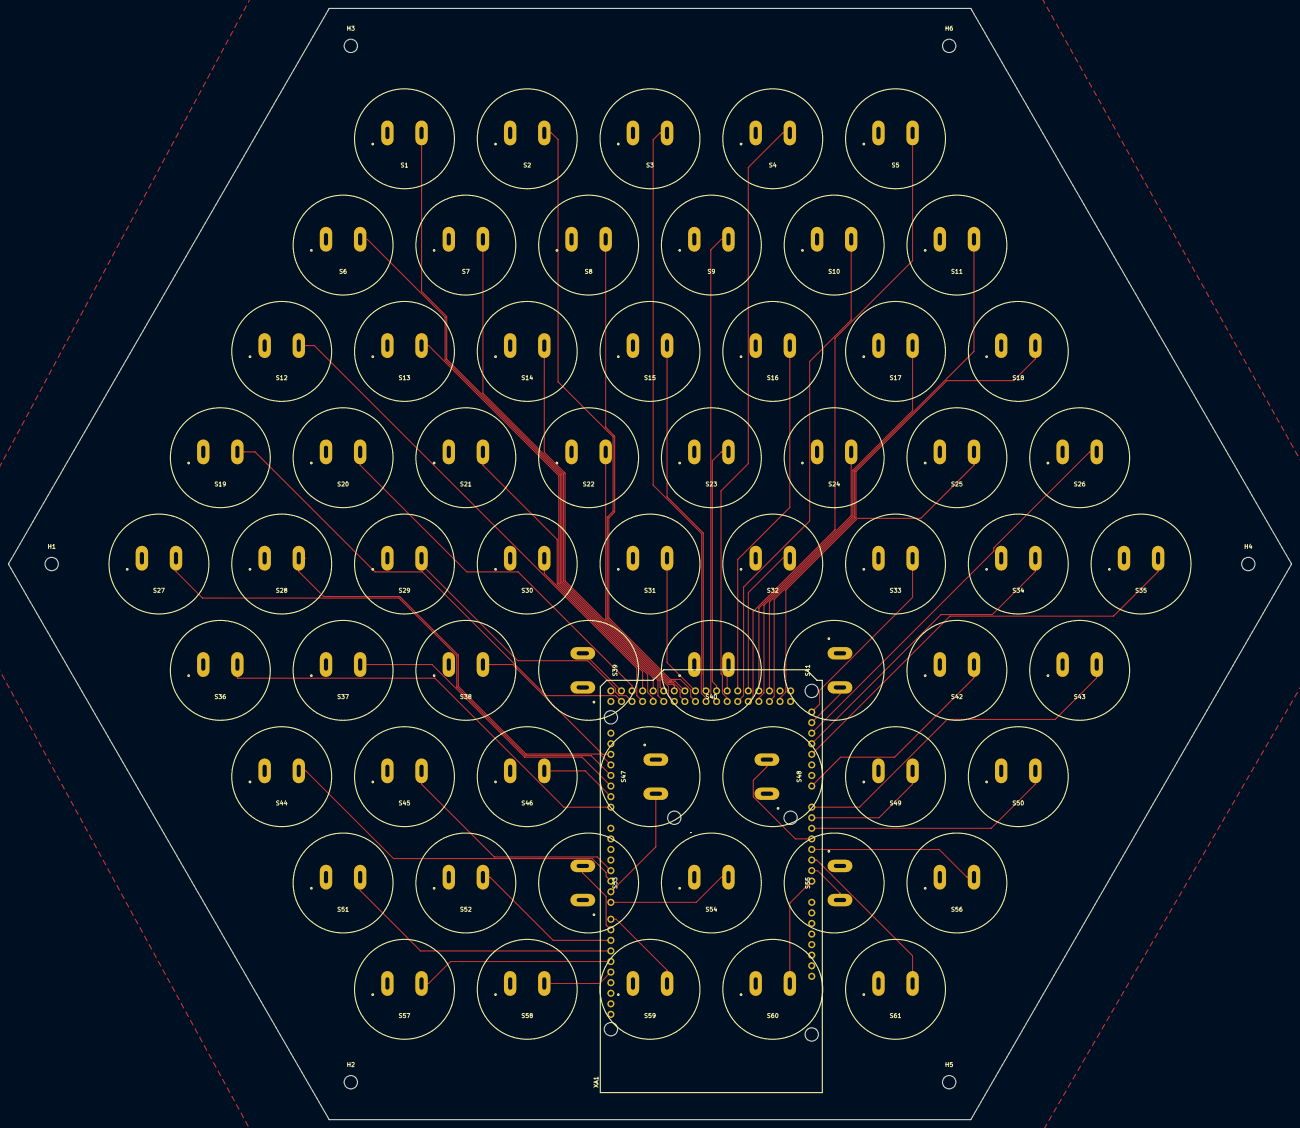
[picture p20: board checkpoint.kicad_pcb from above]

Board: 2 copper layers, 308.3 x 267.0 mm, 68 parts (0 on the bottom side), 62 nets.

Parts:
H1, H2, H3, H4, H5, H6: MountingHole_3.2mm_M3
S1, S2, S3, S4, S5, S6, S7, S8, S9, S10, S11, S12, S13, S14, S15, S16, S17, S18, S19, S20, S21, S22, S23, S24, S25, S26, S27, S28, S29, S30, S31, S32, S33, S34, S35, S36, S37, S38, S39, S40, S41, S42, S43, S44, S45, S46, S47, S48, S49, S50, S51, S52, S53, S54, S55, S56, S57, S58, S59, S60, S61: SANWA-OBSF24; Sanwa-OBSF24-v2
XA1: Arduino_Mega2560_Shield

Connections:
Earth: S1.1, S2.1, S3.1, S4.1, S5.1, S6.1, S7.1, S8.1, S9.1, S10.1, S11.1, S12.1, S13.1, S14.1, S15.1, S16.1, S17.1, S18.1, S19.1, S20.1, S21.1, S22.1, S23.1, S24.1, S25.1, S26.1, S27.1, S28.1, S29.1, S30.1, S31.1, S32.1, S33.1, S34.1, S35.1, S36.1, S37.1, S38.1, S39.1, S40.1, S41.1, S42.1, S43.1, S44.1, S45.1, S46.1, S47.1, S48.1, S49.1, S50.1, S51.1, S52.1, S53.1, S54.1, S55.1, S56.1, S57.1, S58.1, S59.1, S60.1, S61.1, XA1.GND1, XA1.GND2, XA1.GND3, XA1.GND5, XA1.GND6
button-01: S1.2, XA1.D31
button-02: S2.2, XA1.D35
button-03: S3.2, XA1.D38
button-04: S4.2, XA1.D42
button-05: S5.2, XA1.D46
button-06: S6.2, XA1.D30
button-07: S7.2, XA1.D32
button-08: S8.2, XA1.D36
button-09: S9.2, XA1.D40
button-10: S10.2, XA1.D44
button-11: S11.2, XA1.D51
button-12: S12.2, XA1.D26
button-13: S13.2, XA1.D29
button-14: S14.2, XA1.D33
button-15: S15.2, XA1.D39
button-16: S16.2, XA1.D45
button-17: S17.2, XA1.D48
button-18: S18.2, XA1.D50
button-19: S19.2, XA1.D22
button-20: S20.2, XA1.D25
button-21: S21.2, XA1.D28
button-22: S22.2, XA1.D34
button-23: S23.2, XA1.D41
button-24: S24.2, XA1.D49
button-25: S25.2, XA1.D52
button-26: S26.2, XA1.A9, XA1.A13
button-27: S27.2, XA1.D17
button-28: S28.2, XA1.D18
button-29: S29.2, XA1.D24
button-30: S30.2, XA1.D27
button-31: S31.2, XA1.D37
button-32: S32.2, XA1.D47
button-33: S33.2, XA1.A15
button-34: S34.2, XA1.A12
button-35: S35.2, XA1.A11
button-36: S36.2, XA1.D14
button-37: S37.2, XA1.D16
button-38: S38.2, XA1.D19
button-39: S39.2, XA1.D23
button-40: S40.2, XA1.D43
button-41: S41.2, XA1.A14
button-42: S42.2, XA1.A8
button-43: S43.2, XA1.A7
button-44: S44.2, XA1.D5
button-45: S45.2, XA1.D4
button-46: S46.2, XA1.D15
button-47: S47.2, XA1.D6
button-48: S48.2, XA1.A4
button-49: S49.2, XA1.A6
button-50: S50.2, XA1.A5
button-51: S51.2, XA1.D11
button-52: S52.2, XA1.D10
button-53: S53.2, XA1.D9
button-54: S54.2, XA1.D7
button-55: S55.2, XA1.A1
button-56: S56.2, XA1.A3
button-57: S57.2, XA1.D12
button-58: S58.2, XA1.D13
button-59: S59.2, XA1.D8
button-60: S60.2, XA1.A0
button-61: S61.2, XA1.A2

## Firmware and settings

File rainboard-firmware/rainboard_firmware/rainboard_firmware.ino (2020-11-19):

#include <MIDI.h> 
#include <Wire.h>
#include "Adafruit_MCP23017.h"
extern TwoWire Wire1;
// #define TWI_FREQ 400000L in Arduino\hardware\arduino\avr\libraries\Wire\src\utility\twi.h for 400kHz i2c mode

Adafruit_MCP23017 ioExpander;

MIDI_CREATE_INSTANCE(HardwareSerial, Serial, midiUSB);
MIDI_CREATE_INSTANCE(HardwareSerial, Serial1, midiDIN); 

const uint8_t number_of_buttons = 61;
const uint8_t number_of_meta_buttons = 16; // only 12 actual meta buttons (extra 4 are overlap of BTNs 27,25,28, & 35 on IO expander)

const uint8_t modWheel_pin = A9;             
const uint8_t pitchBend_pin = A10;    
const uint8_t softpots_bottom_pin = A11;         

const uint8_t midi_note_max = 127;
const uint8_t midi_note_min = 0;
const uint8_t midi_velocity_max = 127;
const uint8_t midi_velocity_min = 2;
const uint8_t midi_velocity_increment = 25;

uint8_t global_midi_channel = 1;
uint8_t global_midi_velocity = 102;


const uint8_t  button_to_pin[] = 
{31,35,38,42,46,30,32,36,40,44,3,26,29,33,39,45,48,2,22,25,28,34,41,49,0xFF,A13,0xFF,0xFF,24,27,37,47,A15,A12,0xFF,14,16,17,23,43,A14,A8,A7,5,4,15,6,A4,A6,A5,11,10,9,7,A1,A3,12,13,8,A0,A2};
//                             *                   *                   *        *    *                        *          * 
// modified pin assignments from V1 to V3 PCB. 0xFF = placeholder; BTN 27, 35, 25, and 28 moved to io expander.


uint8_t  button_to_wiki[] = 
{42,40,38,36,34,49,47,45,43,41,39,56,54,52,50,48,46,44,63,61,59,57,55,53,51,49,70,68,66,64,62,60,58,56,54,75,73,71,69,67,65,63,61,80,78,76,74,72,70,68,85,83,81,79,77,75,90,88,86,84,82};
                  
uint8_t current_note_map[number_of_buttons] = {0}; 

const uint8_t UP = 1;
const uint8_t DOWN = 0;
const uint8_t ON = 127;
const uint8_t OFF = 0;

 
//scanModWheel
uint8_t ModWheelCurrentPosition;
uint8_t ModWheelPreviousPosition;
uint64_t LastModWheelEventTime;

//scanPitchBend
uint8_t PitchBendCurrentPosition;
uint8_t PitchBendPreviousPosition;
uint64_t LastPitchBendEventTime;

//scanMetaButtons
boolean MetaButtonState[number_of_meta_buttons];
boolean MetaButtonReadyForPress[number_of_meta_buttons];
boolean MetaButtonReadyForRelease[number_of_meta_buttons];
boolean MetaButtonPressDeadZone[number_of_meta_buttons];
boolean MetaButtonReleaseDeadZone[number_of_meta_buttons];
uint64_t LastMetaButtonPressTime[number_of_meta_buttons];
uint64_t LastMetaButtonReleaseTime[number_of_meta_buttons];

boolean MetaButtonPressedFlag[number_of_meta_buttons];
uint8_t MetaButtonIdleCount[number_of_meta_buttons];

//configure timing
const uint64_t meta_button_dead_zone_time = 2;       // in milliseconds
const uint8_t meta_button_idle_period_cycles = 2;    // iterations of scanMetaButtons() @4.56ms (@2.08ms in 400kHz i2c mode)     // originally 100

const uint8_t modWheel_scan_period = 10;             // in milliseconds  
const uint8_t pitchBend_scan_period = 1;             // in milliseconds  

//configure softpot limits
const uint8_t modWheel_ceiling = 20;                 // in samples (total of 1024)
const uint8_t modWheel_floor = 20;
const uint8_t pitchBend_ceiling = 20;
const uint8_t pitchBend_floor = 20;
const uint8_t pitchBend_dead_center = 20;
const uint16_t softpots_max = 1023; 

//configure modes
const boolean PitchInverted = true;

const boolean ModInverted = true;
const boolean IgnoreChannelShift = true;

//scanButtons 
const uint8_t READY_FOR_PRESS = 1;
const uint8_t WAIT_FOR_IDLE_LO = 2;
const uint8_t READY_FOR_RELEASE = 3;
const uint8_t WAIT_FOR_IDLE_HI = 4;

uint8_t ButtonPhase[number_of_buttons];
boolean ButtonState[number_of_buttons];    
uint8_t LastPitchSent[number_of_buttons];  

uint8_t ButtonIdleCountLo[number_of_buttons];
uint8_t ButtonIdleCountHi[number_of_buttons];
uint64_t LastLoDetectedTime[number_of_buttons];
uint64_t LastHiDetectedTime[number_of_buttons];

const uint64_t idle_time_lo = 1;                   // in milliseconds ( minimum 1 )
const uint64_t idle_time_hi = 1;                   // in milliseconds ( minimum 1 )


////////////////////////////////////////////////////////////////////////////////////////////////
void setup(){  

  initIoExpander();                         // init io expander
  initButtons();                            // init buttons  
  initSoftpots();                           // init softpots   
  
  midiUSB.begin(MIDI_CHANNEL_OMNI);         // init midi ports
  midiUSB.turnThruOff();
  midiDIN.begin(MIDI_CHANNEL_OMNI);
  midiDIN.turnThruOn();   

  loadNoteMap(button_to_wiki);
                       
}

//////////////////////////////////////////////////////////////////////////////////////////////////
void loop() {
   
  scanButtons();
  
  scanModWheel();

  scanMetaButtons();
  
  scanPitchBendStandard(); 

  if (midiDIN.read()) {      // MIDI DIN Input echo thru to MIDI USB
     midiUSB.send(midiDIN.getType(), midiDIN.getData1(), midiDIN.getData2(), midiDIN.getChannel());
  }  
 
}

///////////////////////////////////////// SCAN BUTTONS ////////////////////////////////////////////
void scanButtons(){  
  
  uint64_t Now;

  acquireButtons();     // gets all 61 BTNs and stores in ButtonState[] array. including BTN 27, 35, 25, and 28 on the IO expander
    
  Serial.flush();

    for(uint8_t i=0; i<number_of_buttons; i++){      

      if(ButtonPhase[i] == READY_FOR_PRESS){             // if ready for press
          if(ButtonState[i] == 0){                       // and LO detected then it is the first falling edge
              buttonPressEvent(i);                       // initiate button press event
              ButtonPhase[i] = WAIT_FOR_IDLE_LO;         // next button phase
              LastLoDetectedTime[i] = millis();          // mark the time of first falling edge
              ButtonIdleCountLo[i] = 0;                  // reset idle LO counter
          }
      }
      
      else if(ButtonPhase[i] == WAIT_FOR_IDLE_LO){       // if waiting for idle LO
          Now = millis();                          // * Deal with Overflow
          if(ButtonState[i] == 0){                              // if it is LO
              if(ButtonIdleCountLo[i] >= idle_time_lo){               // and idle LO counter has expired
                  ButtonPhase[i] = READY_FOR_RELEASE;                 // next button phase                  
              }
              else if(Now > LastLoDetectedTime[i]){                  // or if time has passed ( > 1ms)               
                  ButtonIdleCountLo[i] = ButtonIdleCountLo[i] + (Now - LastLoDetectedTime[i]);  // update idle LO counter   
                  LastLoDetectedTime[i] = Now;                       // mark the time of last LO detected
              }                 
          }
          else if(ButtonState[i] == 1){                         // if it is HI
              ButtonIdleCountLo[i] = 0;                         // then its a bounce, reset idle LO counter
          }         
      }
      
      else if(ButtonPhase[i] == READY_FOR_RELEASE){             // if ready for release
          if(ButtonState[i] == 1){                              // and HI detected then it is the first rising edge
              ButtonPhase[i] = WAIT_FOR_IDLE_HI;                // next button phase 
              LastHiDetectedTime[i] = millis();                 // mark the time of first rising edge
              ButtonIdleCountHi[i] = 0;                         // reset idle HI counter     
          }       
      }
      
      else if(ButtonPhase[i] == WAIT_FOR_IDLE_HI){              // if waiting for idle HI
          Now = millis();                          // * Deal with Overflow
          if(ButtonState[i] == 0){                              // if it is LO
              ButtonIdleCountHi[i] = 0;                         // then its a bounce, reset idle HI counter
          }
          else if(ButtonState[i] == 1){                         // if it is HI
              if(ButtonIdleCountHi[i] >= idle_time_hi){             // and idle HI counter has expired
                  buttonReleaseEvent(i);                            // initiate button release event
                  ButtonPhase[i] = READY_FOR_PRESS;                 // next button phase                  
              }
              else if(Now > LastHiDetectedTime[i]){                 // or if time has passed ( > 1ms)                
                  ButtonIdleCountHi[i] = ButtonIdleCountHi[i] + (Now - LastHiDetectedTime[i]);  // update idle HI counter 
                  LastHiDetectedTime[i] = Now;                      // mark the time of last HI detected
              }         
          }    
      }
  }     
}

void buttonPressEvent(uint8_t button){
    uint8_t midi_note;
    midi_note = current_note_map[button];                  // lookup pitch 
    midiNoteOn(midi_note, global_midi_velocity);           // send note on
    LastPitchSent[button] = midi_note;                     // store pitch sent
}

void buttonReleaseEvent(uint8_t button){

    midiNoteOff(LastPitchSent[button]);                    // send note off
}

////////////////////////////////////////// LOAD NOTE MAP ////////////////////////////////////////
void loadNoteMap(uint8_t *note_map){

  for(uint8_t i=0; i<number_of_buttons; i++){
    current_note_map[i] = *note_map; 
    note_map++; 
  }  
}

/////////////////////////////////////////// SCAN PITCH//////////////////////////////////////////
void scanPitchBendStandard() {

  static uint16_t pitch_bend_raw;
  static uint16_t softpots_bottom_raw;
  static uint16_t pitch_bend_min;
  static uint16_t pitch_bend_max;
  static uint16_t pitch_bend_center;
  static uint16_t pitch_bend_up_min;
  static uint16_t pitch_bend_down_max;

  if(millis() < LastPitchBendEventTime){                                           // check for rollover
    return;
  }

  if(millis() > LastPitchBendEventTime + pitchBend_scan_period){                    // throttle and debounce
                                          
    softpots_bottom_raw = analogRead(softpots_bottom_pin);                          // get softpots bottom voltage
    pitch_bend_raw = analogRead(pitchBend_pin);                                     // get pitch bend voltage

    pitch_bend_min = softpots_bottom_raw + pitchBend_floor;                             // set lower limit
    pitch_bend_max = softpots_max - pitchBend_ceiling;                                  // set upper limit
    pitch_bend_center = (pitch_bend_min + ((pitch_bend_max - pitch_bend_min) / 2));     // set center             
    pitch_bend_up_min = (pitch_bend_center + (pitchBend_dead_center / 2));              // set pitch bend up lower limit
    pitch_bend_down_max = (pitch_bend_center - (pitchBend_dead_center / 2));            // set pitch bend down upper limit   
    
    if(pitch_bend_raw > softpots_bottom_raw){                                                             // if its not a release

      if((pitch_bend_raw >= pitch_bend_min) && (pitch_bend_raw <= pitch_bend_down_max)){                  // if it is a pitch down
          if(PitchInverted){
            PitchBendCurrentPosition = map(pitch_bend_raw, pitch_bend_min, pitch_bend_down_max, 127, 64); // pitch inverted    
          }
          else if(!PitchInverted){
            PitchBendCurrentPosition = map(pitch_bend_raw, pitch_bend_min, pitch_bend_down_max, 0, 63);   // get pitch down value      
          }                  
      }

      else if((pitch_bend_raw >= pitch_bend_up_min) && (pitch_bend_raw <= pitch_bend_max)){               // if it is a pitch up
          if(PitchInverted){
            PitchBendCurrentPosition = map(pitch_bend_raw, pitch_bend_up_min, pitch_bend_max, 63, 0);     // pitch inverted 
          }
          else if(!PitchInverted){
            PitchBendCurrentPosition = map(pitch_bend_raw, pitch_bend_up_min, pitch_bend_max, 64, 127);   // get pitch up value   
          }                   
      }
             
      if((PitchBendCurrentPosition >= 0) && (PitchBendCurrentPosition <= 127)){                 // if in range         
         if(PitchBendCurrentPosition != PitchBendPreviousPosition){                             // and has changed
            midiPitchBend(PitchBendCurrentPosition);                                            // send midi            
            PitchBendPreviousPosition = PitchBendCurrentPosition;                               // update pitch bend value
            LastPitchBendEventTime = millis();                                                  // update timekeeper
         } 
      }
    } 
    else if(pitch_bend_raw < softpots_bottom_raw){                    // if it is a release  
      if(PitchBendCurrentPosition != 64){                             // and pitch bend not centered
        midiPitchBend(64);                                            // send midi pitch bend center 
        PitchBendPreviousPosition = PitchBendCurrentPosition = 64;    // update pitch bend value
        LastPitchBendEventTime = millis();                            // update timekeeper
      }          
    }
  }   
}

/////////////////////////////////////////// SCAN MOD  ///////////////////////////////////////////
void scanModWheel() {

  static uint16_t mod_wheel_raw;
  static uint16_t softpots_bottom_raw;
  static uint16_t mod_wheel_min;
  static uint16_t mod_wheel_max;

  if(millis() < LastModWheelEventTime){                                           // check for rollover
    return;
  }

  if(millis() > LastModWheelEventTime + modWheel_scan_period){                    // throttle and debounce
                                          
    softpots_bottom_raw = analogRead(softpots_bottom_pin);                        // get softpots bottom voltage
    mod_wheel_raw = analogRead(modWheel_pin);                                     // get mod wheel voltage

    mod_wheel_min = softpots_bottom_raw + modWheel_floor;                         // set lower limit
    mod_wheel_max = softpots_max - modWheel_ceiling;                              // set upper limit
    
    if(mod_wheel_raw > softpots_bottom_raw){                                                   // if its not a release
       ModWheelCurrentPosition = map(mod_wheel_raw, mod_wheel_min, mod_wheel_max, 0, 127);     // get mod wheel value
       if((ModWheelCurrentPosition >= 0) && (ModWheelCurrentPosition <= 127)){                 // if in range
          if(ModInverted){
             ModWheelCurrentPosition = map(ModWheelCurrentPosition, 0, 127, 127, 0);  
          }
          if(ModWheelCurrentPosition != ModWheelPreviousPosition){                             // and has changed
             midiModWheel(ModWheelCurrentPosition);                                            // send midi
             ModWheelPreviousPosition = ModWheelCurrentPosition;                               // update mod wheel value
             LastModWheelEventTime = millis();                                                 // update timekeeper
          } 
       }
    }      
  }   
}

/////////////////////////////////////////  META BUTTON FUNCTIONS /////////////////////////////////////////

// * pitch shifting functions assume BTN1 is lowest pich and BTN61 is highest pitch in notemap
void octaveShift(uint8_t shift_direction){

  if(shift_direction == UP){
    if((current_note_map[60] + 12) < midi_note_max){
      for(uint8_t i=0; i<number_of_buttons; i++){  
        current_note_map[i] = (current_note_map[i]+12);   
      }
    }
  }  
  if(shift_direction == DOWN){
    if((current_note_map[0] - 12) > midi_note_min){
      for(uint8_t i=0; i<number_of_buttons; i++){  
        current_note_map[i] = (current_note_map[i]-12);      
      }
    }  
  }
}

void semitoneShift(uint8_t shift_direction){

  if(shift_direction == UP){
    if((current_note_map[60] + 1) < midi_note_max){
      for(uint8_t i=0; i<number_of_buttons; i++){  
        current_note_map[i]++;   
      }
    }
  }  
  if(shift_direction == DOWN){
    if((current_note_map[0] - 1) > midi_note_min){
      for(uint8_t i=0; i<number_of_buttons; i++){  
        current_note_map[i]--;   
      }
    }  
  }  
}

void velocityShift(uint8_t shift_direction){

  if(shift_direction == UP){
    if(global_midi_velocity <= (midi_velocity_max - midi_velocity_increment)){     
         global_midi_velocity = (global_midi_velocity + midi_velocity_increment);    
    }    
  }  
  if(shift_direction == DOWN){
    if(global_midi_velocity >= (midi_velocity_min + midi_velocity_increment)){   
         global_midi_velocity = (global_midi_velocity - midi_velocity_increment);   
    }    
  }  
}

void channelShift(uint8_t shift_direction){
  if(IgnoreChannelShift == true){
    return;
  }
  if(shift_direction == UP){
     if(global_midi_channel < 16){       
       global_midi_channel++;
     }     
  }  
  if(shift_direction == DOWN){
    if(global_midi_channel > 1){        
       global_midi_channel--;
    }     
  }  
}

/////////////////////////////////////////  META BUTTONS HANDLER /////////////////////////////////////////
void metaButtonHandler(uint8_t meta_button){ 

  switch (meta_button) {

    case 0: // GPIOA.0 J13
      velocityShift(DOWN);     // Velocity - 
      break;
    case 1: // GPIOA.1 J14
      velocityShift(UP);       // Velocity + 
      break;
    case 2: // GPIOA.2 J15
      octaveShift(DOWN);       // Octave - 
      break;
    case 3: // GPIOA.3 J16
      octaveShift(UP);         // Octave +  
      break;
      
    //// * case 4-7 overlap onto BTNs: // GPIOA.4 used for BTN35 // GPIOA.5 used for BTN27 // GPIOA.6 J17 used for BTN28 // GPIOA.7 J18 used for BTN25
    
    case 8: // GPIOB.0 J1
      semitoneShift(UP);       // Semitone +     
      break;
    case 9: // GPIOB.1 J2
      semitoneShift(DOWN);     // Semitone -
      break;
    case 10: // GPIOB.2 J3 
      channelShift(UP);        // Channel +
      break;
    case 11: // GPIOB.3 J4
      channelShift(DOWN);      // Channel -
      break;
    case 12:  // GPIOB.4 J5
      midiCCout(13, ON);
      midiCCout(13, OFF);
      break;
    case 13: // GPIOB.5 J6
      midiCCout(12, ON);
      midiCCout(12, OFF);
      break;    
    case 14: // GPIOB.6 J7   
      ////
      break;
    case 15: // GPIOB.7 J8
      ////      
      break;
    
    default:
      break;
  }
  
}

/////////////////////////////////////////// SCAN META BUTTONS //////////////////////////////////////////
void scanMetaButtons(){   

  for(uint8_t i=0; i<number_of_meta_buttons; i++){             // gets all 16 pins of the IO expander which includes 12 meta buttons 
      MetaButtonState[i] = ioExpander.digitalRead(i);          // and also overlap of BTN 35, 27, 25, and 28 onto GPIOA.4, GPIOA.5, GPIOA.7, GPIOA.6
  }                                                           

  for(uint8_t i=0; i<number_of_meta_buttons; i++){      

      if(!MetaButtonState[i]){                                                      // if button is low
          if(MetaButtonReadyForPress[i]){                                                    // and ready for press                                
              metaButtonHandler(i);                                                          // initiate meta button press event
              MetaButtonPressedFlag[i] = true;
              LastMetaButtonPressTime[i] = millis();                                         // store time
              MetaButtonReadyForPress[i] = false;                                            // press has been processed
              MetaButtonPressDeadZone[i] = true;                                             // now in meta button press dead zone              
          }
          else if(MetaButtonPressDeadZone[i]){                                               // if in meta button press dead zone
              if(millis() >= (LastMetaButtonPressTime[i] + meta_button_dead_zone_time)){     // and meta button press dead zone is over
                  MetaButtonReadyForRelease[i] = true;                                       // ready for release
                  MetaButtonPressDeadZone[i] = false;                                        // out of meta button press dead zone
              }
          }
      }
          
      else {                                                                          // if button is high
          if(MetaButtonReadyForRelease[i]){                                                  // and ready for release                
              ////                                                                           // do nothing but housekeeping on meta button release event
              MetaButtonPressedFlag[i] = false;
              LastMetaButtonReleaseTime[i] = millis();                                       // store time
              MetaButtonReadyForRelease[i] = false;                                          // release has been processed
              MetaButtonReleaseDeadZone[i] = true;                                           // now in meta button release dead zone              
          }  
          else if(MetaButtonReleaseDeadZone[i]){                                             // if in meta button release dead zone
              if(millis() >= (LastMetaButtonReleaseTime[i] + meta_button_dead_zone_time)){   // and meta button release dead zone is over
                  MetaButtonReadyForPress[i] = true;                                         // ready for press
                  MetaButtonReleaseDeadZone[i] = false;                                      // out of meta button release dead zone
              }
          }

          MetaButtonIdleCount[i]++;
          if(MetaButtonIdleCount[i] >= meta_button_idle_period_cycles){
              if(MetaButtonPressedFlag[i]){
                  ////                                                                       // do nothing but housekeeping on forced meta button release event
                  MetaButtonPressedFlag[i] = false;   
              }
              MetaButtonIdleCount[i] = 0;
          }
      }
  }     
}
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

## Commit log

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2020-08-19 3D printed openscad rainboard chassis
    [rainboard_chassis.scad, rainboard_chassis.stl]
2020-08-19 starting v2 of PCB
    [checkpoint.kicad_pcb, pre_scripting.kicad_pcb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]
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2020-09-14 first draft of v2
    [rainboard_newfighter.sch]
2020-09-14 use corrent JST-HX connector
    [rainboard_newfighter.kicad_pcb]
2020-09-17 final board outline dimentions
    [edgecut.dxf, rainboard_newfighter.kicad_pcb]
2020-09-17 move decoupling caps close to ICs
    [rainboard_newfighter-B_Cu.gbr, rainboard_newfighter-B_Mask.gbr, rainboard_newfighter-B_Paste.gbr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]
2020-09-17 Add LCSC JLCPCB part data for each component
    [rainboard_newfighter.sch]
2020-09-17 Move softpot headers to same corner
    [rainboard_newfighter.kicad_pcb]
2020-09-17 Create analog ground network
    [rainboard_newfighter.kicad_pcb, rainboard_newfighter.sch]
2020-09-17 test traces for power and GNDA
    [rainboard_newfighter-B_Cu.gbr, rainboard_newfighter-B_Mask.gbr, rainboard_newfighter-B_Paste.gbr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]
2020-09-17 send MINI IN opto signal through schmitt trigger
    [rainboard_newfighter.kicad_pcb, rainboard_newfighter.sch]
2020-09-17 fixed broken drill-hole
    [rainboard_newfighter-B_Cu.gbr, rainboard_newfighter-B_Mask.gbr, rainboard_newfighter-B_Paste.gbr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]
2020-09-18 v0.2 complete and send to fab
    [rainboard_newfighter-B_Cu.gbr, rainboard_newfighter-B_Mask.gbr, rainboard_newfighter-B_Paste.gbr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]
2020-09-20 Fix footprints so centroid file generates correctly
    [rainboard_newfighter.kicad_pcb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]
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2020-09-21 V0.2 complete and sent to manufacture
    [rainboard_chassis.scad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]
2020-09-28 check in solver for PCB shape
    [rainboard_newfighter.sch]
2020-10-06 final checking for v2
    [plexi_bottom.dxf, rainboard_newfighter.kicad_pcb]
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2020-10-22 v3 of chassis and plexi back
    [plexi_bottom.dxf, rainboard_chassis.scad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]
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2020-10-22 rename kicad directory, use relative paths in kicad libraries
    [checkpoint.kicad_pcb, edgecut.dxf, pre_scripting.kicad_pcb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]
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2020-10-30 start on v0.4 of PCB
    [rainboard_newfighter.kicad_pcb, rainboard_newfighter.sch]
2020-11-01 fix issues with buttons 25 and 28. Improved ground and power network
    [rainboard_newfighter.kicad_pcb, rainboard_newfighter.sch]
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2020-11-05 move velocity to J13 and J14, fix comparison error
    [rainboard_firmware.ino]
2020-11-11 Autorouted v0.4 with thicker power and earth traces
    [rainboard_newfighter-B_Cu.gbr, rainboard_newfighter-B_Mask.gbr, rainboard_newfighter-B_Paste.gbr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]
2020-12-13 Reorganizes project structure and set's up a local symbol library
    [checkpoint.kicad_pcb, edgecut.dxf, pre_scripting.kicad_pcb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]
2020-12-15 Starts new revision, fixes lib path
    Input filtering/protection/etc. ; lots of schematic symbols, most of them paired to a footprint. All saved to project library.
    A few button/RGB combos placed, didn't go 60x yet in case it needs a change.
    [rainboard_newfighter.sch]
2020-12-19 Schematic improvements; LED/buttons and MCU
    Creates subsheet for on-board LED/BUTTON and off-board LED/button
    most electrical connections of 2560.
    most electrical connections of arudino front end
    most electrical connections of LED controller.
    Adds ESD protection to MIDI
    lots of TODO/questions in text to see what progress remains.
    [OFFBOARDBUTTONS.sch, OFFBoardButton.sch, PCBButton.sch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]
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2020-12-31 Schematic nearly finalized; PCB / footprint started
    -Schematic is nearly finished. Needs some footprint associations and verifications.
    -A few open questions remain.
    -some lib updates to go w/ sch improvements
    -
    [MetaButton.sch, MetaButtons.sch, OFFBOARDBUTTONS.sch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]
2021-01-02 Schematic review
    - Updates blocks
    - Removes RGB LEDS from off board
    - Fixes ERC errors
    [rainboard_newfighter.sch]
2021-01-06 Minor schematic and library changes
    Fixes some typos; changes oscillators to be common to all MCUs; SMD for MIDI opto input
    [MetaButtons.sch, PCBMountButtons.sch, rainboard_newfighter.kicad_pcb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]
2021-01-06 Minor schematic and library changes
    Identical to previous commit, some files weren't saved.
    [PCBButton.sch, PCBMountButtons.sch, rainboard_newfighter.sch]
2021-01-07 Changes Micro USB to USB B
    [OFFBOARDBUTTONS.sch, rainboard_newfighter.sch]
2021-01-07 adds power flag to GNDA
    GNDA was failing ERC check. adds a power flag to fix it
    [rainboard_newfighter.sch]
2021-01-13 Removed RGB from buttons, part numbers updated, cleaned up schematic
    [MetaButton.sch, MetaButtons.sch, OFFBOARDBUTTONS.sch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]
2021-01-13 New footprints added
    Updated library format for footprints. Pending sync with layout to add all new footprints
    [PCBButton.sch, PCBMountButtons.sch, rainboard_newfighter.kicad_pcb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]
2021-01-14 Fixing annotations for buttons and meta buttons
    [PCBButton.sch, rainboard_newfighter.kicad_pcb, rainboard_newfighter.sch]
2021-01-14 Moves meta buttons to correct config, adds back on board buttons.
    [PCBButton.sch, PCBMountButtons.sch, rainboard_newfighter.kicad_pcb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]
2021-01-14 position midi DIN, USB, and power barrel
    [rainboard_newfighter.kicad_pcb]
2021-01-14 position J4 through J16
    [rainboard_newfighter.kicad_pcb]
2021-01-18 Footprints fixed, button orgin moved to allow placement of LEDs
    [rainboard_newfighter.kicad_pcb, rainboard_newfighter.sch]
2021-01-18 Swaps over to 5V input supply
    [PCBButton.sch, rainboard_newfighter.kicad_pcb, rainboard_newfighter.sch]
2021-01-19 Modified electrolytics and setup board for layout
    [PCBButton.sch, PCBMountButtons.sch, rainboard_newfighter.kicad_pcb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]
2021-01-19 Forgot to update electrolytic PN
    [PCBMountButtons.sch, rainboard_newfighter.sch]
2021-01-19 Buttons modified for dimensions
    [rainboard_newfighter.kicad_pcb]
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2021-01-22 general placement of leds
    [rainboard_newfighter.kicad_pcb]
2021-01-23 prelim place & route
    deleted extra R's layout & sch
    [PCBButton.sch, PCBMountButtons.sch, rainboard_newfighter.kicad_pcb]
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2021-01-29 Moves meta button connectors to correct spots
    Updates locations for layout to continue
    [PCBButton.sch, rainboard_newfighter.kicad_pcb, rainboard_newfighter.sch]
2021-02-06 position the interfaces, first pass
    [rainboard_newfighter.kicad_pcb]
2021-02-11 routing
    button array routing complete
    [rainboard_newfighter.kicad_pcb]
2021-02-18 move metabuttons, position rear jacks, reduce profile of lightning chassis
    [rainboard_chassis.scad]
2021-02-18 thunder chassis with regular hexagon and snap fit
    [rainboard_chassis_thunder.scad]
2021-02-18 thunder chassis with non-regular hexagon
    [rainboard_chassis_thunder.scad]
2021-02-18 re-organize chassis folder into lightning and thunder
    [chassis_solver.dxf, plexi_bottom.dxf, rainboard_chassis.scad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]
2021-02-18 reduce size of thunder chassis
    [chassis_solver.dxf, rainboard_chassis_thunder.scad, rainboard_chassis_thunder.stl]
2021-02-21 Review and gerber export of v1a
    [PCBButton.sch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]
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
